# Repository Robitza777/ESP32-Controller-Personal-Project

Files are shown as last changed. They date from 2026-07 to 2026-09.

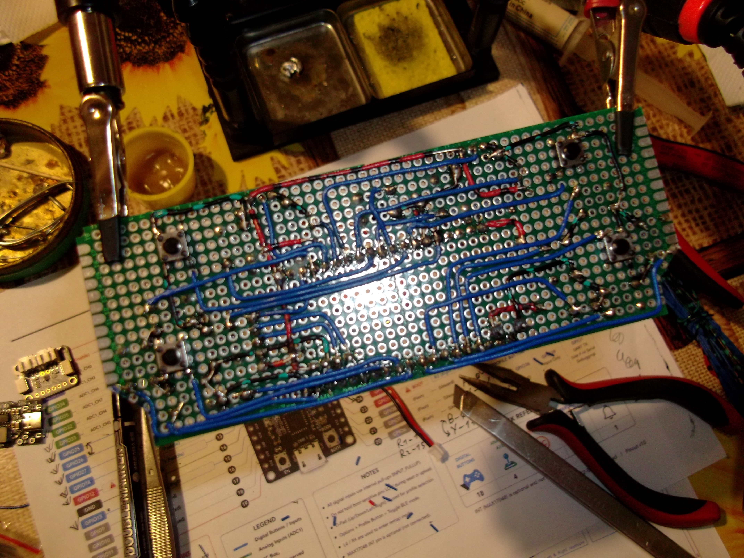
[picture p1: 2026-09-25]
media/hardware/Wiring.JPG

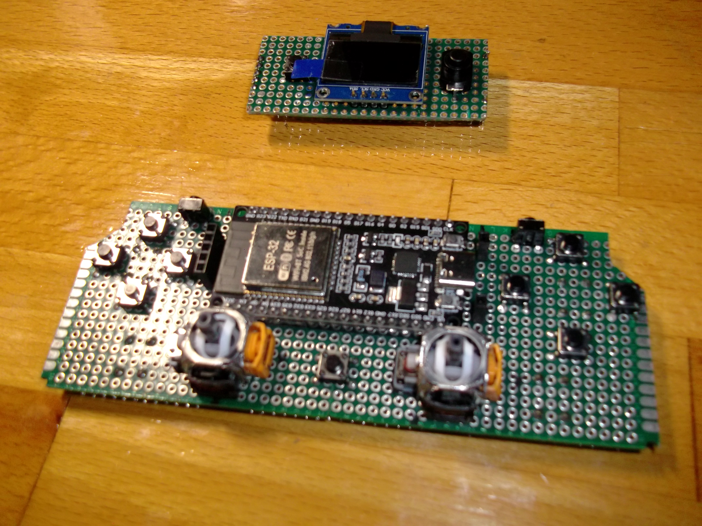
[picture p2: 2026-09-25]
media/hardware/Parts_Placement.JPG

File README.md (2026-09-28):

# ESP32-Controller-Personal-Project

A custom Bluetooth Low Energy gamepad controller built from scratch, combining hardware design, firmware development, and a fully 3D-printed enclosure. The goal of this project is a wireless gamepad that works **natively** in modern games (e.g. Fortnite) via true XInput support, with a flexible multi-profile system for gaming, desktop, and media use cases.

## Overview

This is not a modded off-the-shelf controller. Every major aspect is custom-designed:

* **Hardware** – ESP32-based electronics with hall-effect joysticks, dedicated battery management and fuel gauge, OLED status display, and a custom power system.
* **Firmware** – Native XInput over Bluetooth LE (not generic HID/DirectInput) together with keyboard, mouse, and media keys, featuring up to 16 profiles that are fully editable on the controller itself, battery monitoring, and automatic power-off.
* **Enclosure** – Fully custom 3D-printed shell, modeled in Blender and optimized around the project's hardware layout.

## Features

### Native XInput over Bluetooth LE

Unlike generic HID/DirectInput gamepads, this controller uses the [ESP32-BLE-CompositeHID](https://github.com/Mystfit/ESP32-BLE-CompositeHID) library to present itself as a native XInput device. This matters because many modern games, **Fortnite** being a notable example, do not recognize DirectInput controllers at all and previously required workarounds such as **x360ce**. With native XInput support, no additional software is needed.

The same Bluetooth connection also carries a keyboard, a 5-button mouse with vertical and horizontal scrolling, media keys, and system keys (sleep, power down). Any button can send any of them at any time, without re-pairing or switching modes. In Windows, the controller appears as **Robitza's ESP32 Gamepad**.

### Low Latency

Responsiveness is the firmware's top priority:

* All inputs are scanned at a fixed **1 kHz** on a dedicated CPU core.
* A button press registers on the very first sample (eager debounce, no added delay).
* The controller requests the shortest Bluetooth LE connection interval (**7.5 ms**) and sends a report only when something changed.
* Display, battery, and storage work runs on the other CPU core and never delays input.

### Profiles and Presets

The controller holds up to **16 profiles**, switchable at any time via the dedicated profile button. On first boot, it starts with four built-in presets:

| Profile | Description |
| --- | --- |
| **GAMEPAD**  | Native XInput controller. L4 acts as View, R4 as the Xbox Guide button. |
| **KB+MOUSE** | PC games without controller support (FPS layout). The left stick acts as WASD, the right stick controls the mouse, R2 / L2 are the left / right mouse buttons. |
| **MEDIA** | Desktop and media control: cursor, scrolling, volume, track control, play/pause, Alt+Tab, Win+D, copy and paste. |
| **HYBRID** | Standard XInput controller, plus a second layer while R4 is held: mouse, scrolling, clicks, Enter / Esc, and media keys, to operate the PC without leaving the game profile. |

Every profile can be edited, and new ones created, directly on the controller:

* Each button can send up to **three actions at once** (e.g. Ctrl+C, LB+RB, or an Xbox button plus a key), chosen from all Xbox buttons, the full keyboard (including F13–F24 and the numpad), mouse buttons and scrolling, and media, launch, browser, and system keys.
* Button modes: **Normal**, **Toggle** (press on / press off), and **Turbo** (1–20 presses per second).
* **RTZ layer** ("Robitza-Shift"): a button can switch the whole controller to a second set of mappings while held, or lock it in Toggle mode, similar to Razer HyperShift.
* Each stick can act as the left or right Xbox stick, a mouse, a scroll wheel, or four separate directions (WASD, arrow keys, D-pad...), with its own deadzone and speed.
* Any button or stick can be disabled.

### Profile Button

A dedicated profile button (GPIO36) switches profiles without any menu:

* **Short press** → Next profile.
* **Double press** → Back to the previous profile.
* **Hold + A / B / X / Y** → Jump to profile 1 / 2 / 3 / 4.
* **Hold for 3 seconds** → Open the configuration menu.

Buttons pressed while the profile button is held are never sent to the host.

### On-Controller Configuration Menu

All settings are changed directly on the controller's OLED screen, with no app, website, or reflashing required:

* **D-pad or left stick** to navigate, **A** to select, **B** to go back, **L1 / R1** to jump through long lists.
* To edit a button, simply **press it**.
* Create profiles from a preset or a copy of another profile, rename, reorder, and delete them.
* Controller settings: display brightness and timeout, automatic power-off times, stick recalibration, and Bluetooth pairing reset.
* Changes are kept only when leaving the menu with **Save**. While the menu is open, the host receives no input.

All profiles and settings are stored in the ESP32's Non-Volatile Storage (NVS), remaining available after power loss. The complete menu is described in the [User Guide](docs/UserGuide.md).

### OLED Status Display

A 0.96" SSD1306 OLED provides quick access to important controller information, including:

* Active profile name and number
* Battery percentage and a 4-bar indicator
* Charging status
* Bluetooth connection status
* RTZ layer and Toggle indicators

After a profile switch, the new name is shown full screen for a second. The screen switches off after a configurable time without input (30 seconds by default), and any input wakes it up.

### Battery Monitoring

A dedicated MAX17048 fuel gauge, connected directly across the battery terminals, provides accurate state-of-charge readings rather than relying solely on battery voltage.

The battery level is also reported to Windows and shown next to the device in the Bluetooth settings. At 5%, the controller shows a full-screen warning; at 2%, it switches itself off to protect the Li-Po cell.

### Power Management

The controller switches itself off after a configurable time without input (5 minutes by default, set separately for connected and not connected), after a 10-second on-screen countdown that any input cancels.

Rather than fighting the automatic shutdown behavior of the IP5306 / FM5324UI power module, which cuts its output when the load current stays too low, the firmware relies on it: the ESP32 enters deep sleep, the power module switches its 5 V output off about 30 seconds later, and the controller draws no power until the on/off switch is toggled.

### Hall-Effect Joysticks

Hall-effect joystick modules eliminate potentiometer wear and significantly reduce stick drift compared to traditional analog sticks.

The firmware measures each stick's center at power-on, scales every direction separately, and maps the sticks to a true circle (0% circularity error in a gamepad tester), with a per-profile radial deadzone. The centers can be measured again from the menu at any time.

## Hardware Platform

| Component | Purpose |
| --- | --- |
| ESP32 WROOM DevKit (38-pin) | Main microcontroller |
| IP5306 / FM5324UI | Battery charging & power management  |
| MAX17048 | Battery fuel gauge (state-of-charge) |
| SSD1306 0.96" OLED (I²C) | Status display |
| Ginfull R-5B / L-5C | Hall-effect joystick modules |
| Custom 3D-printed enclosure | Full physical housing |

Full schematics, pinouts, power design, bill of materials, and datasheets are available in [`hardware/`](hardware/).

## Firmware

Built with [PlatformIO](https://platformio.org/) targeting the ESP32 and powered by the [ESP32-BLE-CompositeHID](https://github.com/Mystfit/ESP32-BLE-CompositeHID) library, allowing simultaneous native XInput and keyboard/mouse HID functionality over Bluetooth Low Energy.

The firmware (version **1.0.0**) follows a modular architecture responsible for:

* Input processing
* Profile management
* On-controller configuration menu
* Bluetooth communication
* OLED display control
* Battery monitoring
* Power management
* Persistent storage (NVS)

Two builds are available: **release** (the default, flashed on the controller) and **debug** (the same firmware plus a detailed serial log for troubleshooting).

See [`firmware/`](firmware/) for the source code and build instructions, [`docs/Software.md`](docs/Software.md) for implementation details, and [`docs/Architecture.md`](docs/Architecture.md) for how the modules work together.

## Enclosure

The controller's shell is fully custom-designed and 3D-printed. Its overall shape and ergonomic layout are inspired by the **Alpakka 1 controller** by [Input Labs](https://github.com/inputlabs/cad), while the internal layout, mounting system, and component placement are unique to this project.

Blender source files, STEP exports, and printable STL models are available in [`enclosure/`](enclosure/).

## Repository Structure

```text
ESP32-Controller-Personal-Project/
├── firmware/      — PlatformIO firmware
├── hardware/      — Schematics, pinouts, power design, BOM, datasheets
├── enclosure/     — Blender source, STEP and STL exports
├── docs/          — User guide and technical documentation
├── media/         — Photos and videos of the enclosure, firmware and hardware
└── tools/         — Input tester
```

## Documentation

* [User Guide](docs/UserGuide.md)
* [Build Guide](docs/BuildGuide.md)
* [Hardware](docs/Hardware.md)
* [Software](docs/Software.md)
* [Architecture](docs/Architecture.md)
* [Development Log](docs/DevelopmentLog.md)
* [Future Plans](docs/FuturePlans.md)

## Project Status

Firmware **1.0.0** is complete and tested on the real hardware: all inputs, the four presets, the configuration menu, Bluetooth reconnection, battery monitoring, and automatic power-off. The project remains under active development.

See:

* [`CHANGELOG.md`](CHANGELOG.md) for released milestones.
* [`docs/DevelopmentLog.md`](docs/DevelopmentLog.md) for ongoing development progress.
* [`docs/FuturePlans.md`](docs/FuturePlans.md) for ideas being considered.

## Contributing

Contributions, suggestions, and bug reports are welcome.

Please read [`CONTRIBUTING.md`](CONTRIBUTING.md) before opening issues or pull requests.

## License

See [`LICENSE`](LICENSE) for licensing information.

## Acknowledgements

* Enclosure design inspired by the [Alpakka 1 controller](https://github.com/inputlabs/cad) by **Input Labs**.
* Built on top of the [ESP32-BLE-CompositeHID](https://github.com/Mystfit/ESP32-BLE-CompositeHID) library by **Mystfit**, included in [`firmware/lib/`](firmware/lib/) with local changes.
* Bluetooth LE stack: [NimBLE-Arduino](https://github.com/h2zero/NimBLE-Arduino) by **h2zero**.
* OLED graphics: [U8g2](https://github.com/olikraus/u8g2) by **olikraus**.
* Fuel gauge driver: [SparkFun MAX1704x Fuel Gauge Arduino Library](https://github.com/sparkfun/SparkFun_MAX1704x_Fuel_Gauge_Arduino_Library) by **SparkFun Electronics**.

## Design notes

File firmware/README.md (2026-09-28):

# Firmware

PlatformIO project for the controller's ESP32, firmware version **1.0.0**. How the firmware works is described in [`docs/Software.md`](../docs/Software.md) and [`docs/Architecture.md`](../docs/Architecture.md); how to use the controller in [`docs/UserGuide.md`](../docs/UserGuide.md).

## Requirements

* [VS Code](https://code.visualstudio.com/) with the [PlatformIO IDE](https://platformio.org/install/ide?install=vscode) extension (or the PlatformIO Core CLI).
* A USB cable to the ESP32 DevKit (CP2102 USB-serial chip; Windows may need the Silicon Labs CP210x driver).

Everything else (the ESP32 toolchain, Arduino core, and libraries) is downloaded by PlatformIO on the first build, at the exact versions pinned in [`platformio.ini`](platformio.ini).

## Build and Flash

Open **this folder** (`firmware/`, the one containing `platformio.ini`) in VS Code, not the repository root.

| Build | What it is | Command |
|---|---|---|
| `release` | The default. What stays on the controller: no serial output. | `pio run -t upload` |
| `debug` | The same firmware, plus a serial log: Bluetooth pairing and connection, battery readings, power decisions, saves. | `pio run -e debug -t upload` |

In VS Code, the same actions are under **PlatformIO → Project Tasks → release / debug → Upload**. To read the debug log, open the serial monitor (`pio device monitor`, 115200 baud) after uploading.

Uploading only replaces the program: saved profiles, settings, and Bluetooth pairings are kept.

**Don't hold any button while the board resets or is being flashed.** A, X, D-pad Up, R2, and R4 are on ESP32 boot pins (see [`Pinout.md`](../hardware/pinout/Pinout.md)).

### First Flash

The project uses its own partition table ([`partitions.csv`](partitions.csv)) with a larger settings store (NVS, 128 KB). If the board was previously flashed with a different partition table, erase it once with **PlatformIO → Project Tasks → release → Platform → Erase Flash** before uploading. Erasing also removes the Bluetooth pairing, so the controller must be removed and paired again in Windows.

## Folder Structure

```text
firmware/
├── platformio.ini     — Board, libraries (pinned versions), release and debug builds
├── partitions.csv     — Flash layout: app 3 MB, NVS 128 KB
├── include/           — Module headers: public interface and design notes
│   ├── Config.h       — Every pin, address, timing and threshold
│   └── ...
├── src/               — Module implementations; main.cpp starts the tasks and connects the modules
└── lib/
    └── ESP32-BLE-CompositeHID/   — Vendored library with local changes (see its VENDORED.md)
```

| Module | Files | Responsibility |
|---|---|---|
| main | `main.cpp` | Starts the input and UI tasks, passes data between modules, runs the menu hand-off and the power-off sequence |
| InputReader | `InputReader.h/.cpp` | Buttons and sticks: debounce, stick calibration, circular mapping, deadzone |
| ProfileButton | `ProfileButton.h/.cpp` | Profile button gestures |
| Profiles | `Profiles.h/.cpp`, `ProfileTypes.h` | Presets, profile list, and the engine that turns inputs into outputs |
| ConfigMenu | `ConfigMenu.h/.cpp`, `MenuView.h` | The on-controller configuration menu |
| ActionCatalog | `ActionCatalog.h/.cpp`, `HidUsages.h` | Named, grouped action lists offered by the menu |
| BleOutput | `BleOutput.h/.cpp` | Bluetooth LE HID device: Xbox controller, keyboard, media keys, mouse |
| Display | `Display.h/.cpp` | OLED: status screen, menu, alerts |
| BatteryMonitor | `BatteryMonitor.h/.cpp` | MAX17048 fuel gauge |
| PowerManager | `PowerManager.h/.cpp` | Automatic power-off and battery protection |
| Storage | `Storage.h/.cpp` | Profiles and settings in NVS |
| (shared) | `ControllerTypes.h`, `Log.h` | Data types passed between modules, debug logging |

## Libraries

| Library | Version | Used for |
|---|---|---|
| [ESP32-BLE-CompositeHID](https://github.com/Mystfit/ESP32-BLE-CompositeHID) | commit `032b064`, vendored in `lib/` | Xbox controller + keyboard + mouse over one BLE connection |
| [NimBLE-Arduino](https://github.com/h2zero/NimBLE-Arduino) | 2.5.1 | Bluetooth LE stack |
| [Callback](https://github.com/tomstewart89/Callback) | 1.1 | Required by ESP32-BLE-CompositeHID |
| [U8g2](https://github.com/olikraus/u8g2) | 2.36.18 | SSD1306 OLED |
| [SparkFun MAX1704x Fuel Gauge](https://github.com/sparkfun/SparkFun_MAX1704x_Fuel_Gauge_Arduino_Library) | 1.0.4 | MAX17048 fuel gauge |

Platform: `espressif32 @ 7.0.1` (Arduino core 2.0.17, ESP-IDF 4.4), C++17.

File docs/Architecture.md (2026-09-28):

# System Architecture

## Overview

The ESP32 Controller firmware is structured as a modular embedded system where hardware input, profile logic, persistent configuration, BLE communication, power monitoring, and user feedback are separated into independent components.

The architecture is designed around a central control flow, split across the ESP32's two CPU cores:

```
CORE 1 — input task, every 1 ms
-------------------------------
Hardware Inputs
      |
      v
InputReader
      |
      v
ProfileButton / Profiles
      |
      +----------------------------+
      |                            |
      v                            | status snapshot
BleOutput                          | (profile, layer, last activity)
      |                            |
      v                            |
Bluetooth LE HID                   |
                                   |
CORE 0 — UI task, every 20 ms      |
-----------------------------      |
main.cpp (UI loop) <---------------+
      |
      +----> PowerManager
      |
      +----> ConfigMenu ----> Storage ----> ESP32 NVS
      |
      +----> Display -------> SSD1306 OLED
      |
      +----> BatteryMonitor <---- MAX17048 <---- Battery
```

The main firmware entry point (`main.cpp`) acts as the orchestrator, initializing modules and coordinating communication between them.

---

# Task Layout

The firmware runs two FreeRTOS tasks, one per CPU core. Responsiveness comes first: nothing slow is allowed on the path from a button to the Bluetooth report.

| Task | Core | Priority | Period | Work |
|---|---|---|---|---|
| **input** | 1 | high (10) | 1 ms, fixed (`vTaskDelayUntil`) | `InputReader` → `ProfileButton` / `Profiles` → `BleOutput` |
| **UI** | 0 | low (1) | 20 ms | `Display`, `BatteryMonitor`, `PowerManager`, `ConfigMenu`, `Storage` writes |

* The NimBLE Bluetooth host also runs on core 0, above the UI task, so slow UI work never delays Bluetooth either.
* A full OLED frame takes about 23 ms of I²C traffic, and a flash write can stall both cores; both happen only in the UI task, and the display redraws only when something shown has changed.
* The UI task is the **only** user of the I²C bus, so the bus needs no locking.
* The input path never blocks: no `delay()`, no I²C, no flash writes, no serial output.
* The input task publishes a small status snapshot (active profile, layer and toggle state, time of the last activity) every cycle; the UI task reads it every cycle. Both copy a few bytes under a spinlock, so neither side waits noticeably.

Measured input cycle: about 170 µs with nothing to send, about 0.5 ms when a report goes out, rarely up to about 1 ms.

---

# Firmware Layers

## Application Layer

### main.cpp

`main.cpp` is responsible for:

* Loading the saved profiles and settings, initializing all firmware modules, and starting the two tasks.
* Running the input loop and the UI loop.
* Coordinating input processing, profile handling, BLE output, and display updates.
* Handing the profile list over to the configuration menu and back (see below).
* Running the power-off sequence.

Individual modules should not directly depend on each other where possible. Communication should happen through clearly defined interfaces: modules exchange plain data structures (`InputState`, `OutputReport`, `BatteryStatus`, `Profile`...) and `main.cpp` passes them along.

---

# Input Layer

## InputReader

The `InputReader` module handles all physical controller inputs.

Responsibilities:

* Reading digital button states (both GPIO registers in one go).
* Reading analog joystick values (ADC1 through the IDF low-level HAL, oversampled).
* Applying joystick calibration, circular mapping, and deadzone processing.
* Eager debouncing, and the ESP32 GPIO36/39 errata workaround.
* Converting raw hardware values into normalized controller data.

Input flow:

```
Buttons
Joysticks
   |
   v
InputReader
   |
   v
InputState (18 buttons as a bitmask, 4 axes in -32767..32767, +X right, +Y up)
```

The module abstracts the physical GPIO layout from the rest of the firmware.

---

# Profile System

## Profiles

The profile system controls how controller inputs are interpreted.

Built-in presets (read-only templates in flash):

* GAMEPAD
* KB+MOUSE
* MEDIA
* HYBRID

The user's profile list (up to 16) starts as one profile per preset and is then edited in the configuration menu. The profile layer receives normalized controller input and decides how it should be translated, through the active profile's layer (base or RTZ).

Example:

```
Joystick Movement
        |
        v
     Profiles
        |
        +------> XInput Axis
        |
        +------> Mouse Movement / Scroll
        |
        +------> Keyboard Keys (4-way mode)
```

The result is one `OutputReport` per input cycle: the complete state the host should see (Xbox controller, keyboard, consumer keys, system keys, mouse).

---

# Profile Button State Machine

## ProfileButton

The profile button provides access to profile switching and configuration functions without requiring external software.

State flow:

```
Normal Operation

      |
      +---- Short press ----------------> Next profile
      |
      +---- Double press ---------------> Previous profile
      |
      +---- Hold + A / B / X / Y -------> Profile 1 / 2 / 3 / 4
      |
      | Hold 3 s alone
      v

Configuration Menu

      |
      | Hold 3 s again → Save / Discard / Keep editing
      v

Normal Operation
```

Buttons pressed while the profile button is held are kept from the host until they are released.

---

# Configuration Menu

## ConfigMenu, MenuView, ActionCatalog

The configuration menu runs in the UI task:

* `ConfigMenu` holds the menu logic: pages, cursor, the edits.
* `MenuView` is a text-only description of one screen (title, rows, values, cursor). `ConfigMenu` fills it, `Display` draws it: the menu logic never deals with fonts or pixels.
* `ActionCatalog` holds the named, grouped action lists the menu offers (None, RTZ layer, Gamepad, Keyboard, Mouse, Media & system).

While the menu is open, the input task sends the host a neutral report and forwards the buttons and the left stick to the menu. The profile list is handed over between the two tasks with a small state machine, so that only one task works on it at a time:

```
Closed
   |
   | Profile held 3 s: the input task copies the profiles into the menu's workspace
   v
Open  ---- the UI task edits the workspace; the host receives a neutral report
   |
   +---- Save ------> UI task writes the changes to NVS
   |                        |
   |                        v
   |                  Saved: the input task takes the new list into Profiles
   |
   +---- Discard ---> Discarded: the input task keeps its profiles
   |
   v
Closed
```

The workspace also carries the display and power settings; display changes are previewed live while the menu is open.

---

# Storage Layer

## Storage

The storage module provides persistent configuration using ESP32 NVS (Non-Volatile Storage).

Stored data includes:

* The profile list (up to 16 profiles, with a format version).
* Active profile selection.
* Display settings (brightness, screen timeout, name popup).
* Automatic power-off times.

Storage flow:

```
Configuration Menu (Save)
Profile switch (after 3 s)
        |
        v
Storage Module (UI task only)
        |
        v
ESP32 NVS
```

Settings remain available after power loss or restart. The Bluetooth pairings are stored separately by NimBLE.

---

# Communication Layer

## BleOutput

The `BleOutput` module acts as an abstraction layer over the BLE HID implementation.

Responsibilities:

* Sending XInput reports.
* Sending keyboard, consumer (media) and system key reports.
* Sending mouse reports.
* Reporting the battery level to the host.
* Erasing the pairings, and closing the connection before a power-off.

Flow:

```
OutputReport
        |
        v
   BleOutput (a report per device, only when it changed)
        |
        v
ESP32-BLE-CompositeHID
        |
        v
NimBLE ----> Bluetooth LE Device (Xbox controller + keyboard + mouse)
```

The system supports simultaneous controller and HID functionality through the ESP32-BLE-CompositeHID library.

---

# Display Layer

## Display

The OLED display provides user feedback.

Displayed information includes:

* Active profile (name and number), with a full-screen popup after a switch.
* Battery status (percentage, bars, charging).
* Bluetooth connection status.
* RTZ layer and Toggle indicators.
* The configuration menu.
* Full-screen alerts (power-off countdown, battery warnings).

Flow:

```
Status snapshot + BatteryStatus    MenuView    Power alert
             |                        |             |
             v                        v             v
                         Display Module
                               |
                               v
                          SSD1306 OLED
```

The display communicates through the shared I²C bus. It is mounted rotated 180°, redraws only when something shown has changed, and switches off after the configured time without activity.

---

# Battery Monitoring Layer

## BatteryMonitor

The battery monitoring system uses the MAX17048 fuel gauge.

Responsibilities:

* Reading battery state-of-charge every 5 seconds.
* Detecting charging from the gauge's charge rate.
* Providing battery information to the display, the power manager, and the host.
* Handling battery monitoring independently from the charging/power management circuit.

Flow:

```
Battery
   |
   v
MAX17048
   |
   v
BatteryMonitor
   |
   +----> Display
   |
   +----> PowerManager
   |
   +----> BleOutput (Battery Service)
```

---

# Hardware Communication

## I²C Bus

The controller uses a shared I²C bus at 400 kHz:

```
ESP32
 |
 +---- SDA GPIO21
 |
 +---- SCL GPIO22
        |
        +---- SSD1306 OLED (0x3C)
        |
        +---- MAX17048 (0x36)
```

Both devices operate on different I²C addresses and can coexist on the same bus. Only the UI task uses the bus.

---

# Power Management

## PowerManager

The power management module decides when to warn the user and when to power off:

* Automatic power-off after the configured time without activity, with a 10-second countdown.
* Battery critical warning at 5%.
* Automatic power-off at 2% to protect the battery.

Power-off sequence (`main.cpp`):

```
PowerManager: power off
        |
        v
Input task stops sending
        |
        v
OLED off, Bluetooth connection closed
        |
        v
ESP32 deep sleep (no wake-up source)
        |
        v
Load below the power module's threshold ----> 5 V output switched off (~30 s later)
        |
        v
Controller off until the on/off switch is toggled
```

The firmware can switch the controller off, but not on. Light sleep is not used while the controller is on, because the lower current draw would make the power module cut the power in the middle of use.

---

# Design Principles

The firmware architecture follows these principles:

* **Responsiveness first** — nothing on the path from a button to the Bluetooth report may block or wait for slow work.
* **Modularity** — each hardware/software function has its own module.
* **Separation of concerns** — input processing, output generation, storage, and display logic remain independent.
* **Hardware abstraction** — physical GPIO assignments should not leak into higher-level logic; every pin, address, and timing lives in `Config.h`.
* **Graceful degradation** — the controller keeps working if the display or the fuel gauge is missing.
* **Maintainability** — new profiles, mappings, and features should be added without rewriting core functionality.
* **Expandability** — the architecture supports future features such as a companion configuration tool, macros, and OTA updates.

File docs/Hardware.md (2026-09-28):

# Hardware Overview

## Core Components

| Component | Role |
|---|---|
| ESP32 WROOM DevKit (38-pin, CP2102) | Main microcontroller, handles input reading, BLE communication, and firmware logic |
| Ginfull R-5B / L-5C hall-effect joysticks | Analog stick input, chosen for durability and drift resistance over potentiometer sticks |
| MAX17048 | Battery fuel gauge (I²C `0x36`) — provides accurate state-of-charge readings |
| IP5306 / FM5324UI | Battery charging and 5 V power delivery |
| SSD1306 OLED 128x64 (I²C `0x3C`) | Status display and configuration menu, mounted rotated 180° |
| 1S Li-Po battery, 3.7 V 2500 mAh | Power source |
| Custom protoboard | Houses all electronics |

## Power Architecture

- The **IP5306 / FM5324UI** module charges the 1S Li-Po battery and delivers 5 V to the ESP32 DevKit's `5V` pin.
- A physical **on/off switch** in the 5 V line, between the power module and the ESP32, disconnects the system power completely. The module's `K` (KEY) pin is **not used**: it was tested and did not provide the expected power control behavior in this hardware implementation.
- The power module switches its 5 V output off by itself when the load current stays below its minimum (about 45–50 mA) for about 30 seconds. While the controller is on, the ESP32 with its Bluetooth radio draws enough to stay above that threshold, so the firmware doesn't use light sleep or CPU down-clocking. The firmware uses this behavior for its **automatic power-off**: the ESP32 enters deep sleep, the module cuts the 5 V output about 30 seconds later, and the on/off switch (off, then on) starts the controller again. The firmware can switch the controller off, but not on.
- The **MAX17048** fuel gauge is wired directly across the battery terminals, in parallel with the charging circuit. This placement means it reads the battery's true state without interfering with charging, and it keeps tracking the battery while the controller is switched off. Its `INT` pin is not connected.

<!-- Full details in [PowerDesign.md](../hardware/power/PowerDesign.md) and [BatteryCalibration.md](../hardware/power/BatteryCalibration.md). -->

## GPIO Considerations

GPIO36 (used for the profile button) and GPIO39 (D-pad Down) are **input-only pins with no internal pull-up**, requiring an external 10kΩ pull-up resistor to 3.3V each. This is a hard hardware constraint of the ESP32 and must be accounted for in the wiring.

- **GPIO2** (X button) is tied to the DevKit's on-board LED and needs an external 1 kΩ pull-up resistor to 3.3 V to be read reliably.
- **Boot strapping pins** — GPIO0 (A), GPIO2 (X), GPIO5 (D-pad Up), GPIO12 (R4) and GPIO15 (R2) affect the ESP32 boot process: their buttons must not be held while the controller is switched on, reset, or flashed.
- **ESP32 errata** — GPIO36 and GPIO39 can briefly read LOW when the ADC powers up. The firmware works around it (the ADC stays powered and these two pins need two LOW readings in a row).
- **Joysticks** use ADC1 (GPIO32–35), because ADC2 can't be used while Bluetooth is active. The Ginfull sticks' raw output covers the full 0–4095 range and saturates at both ends before full travel; the firmware calibrates and scales it.
- **L2 / R2** are digital buttons, not analog triggers.

Full pin assignments are documented in [`Pinout.md`](../hardware/pinout/Pinout.md).

## Assembly Notes

The ESP32 DevKit sits in female headers (socketed, not soldered). A board that isn't pushed fully into its headers can lose contact on its `5V` pin under vibration, which shows up as random power-offs and can also disturb the stick readings (a stick that no longer rests at zero). If random resets or power-offs appear, check the seating of the board first.

## Enclosure

All electronics — ESP32, protoboard, joysticks, power management, fuel gauge, and OLED are held together by the **back shell** (`green_back.stl`) and the **front shell** (`black_front.stl`), which are purely mechanical, providing only cutout windows for buttons, sticks, and the display; no components attach to them directly.

The OLED display, profile button and on/off switch are mounted on a suspended support platform.

The overall shell shape and ergonomics are inspired by the **Alpakka 1 controller by Input Labs**, adapted to this project's specific internal component layout.

See [`enclosure/`](../enclosure/) for 3D source files and exports, and [`hardware/schematics/`](../hardware/schematics/) for circuit schematics.

## Datasheets

Component datasheets are available in [`hardware/datasheets/`](../hardware/datasheets/):
- ESP32
- MAX17048
- IP5306 / FM5324UI
- SSD1306

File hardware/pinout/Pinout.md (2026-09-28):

# GPIO Pinout

This document describes the GPIO assignments used by the ESP32-Controller-Personal-Project.

---

## Digital Inputs

| Function | GPIO | Notes |
|---|---|---|
| A Button (Down) | GPIO0 | Boot strapping pin (flashing mode). Do not hold during power-on or firmware flashing. |
| B Button (Right) | GPIO17 | Standard digital input. Uses internal `INPUT_PULLUP`. |
| X Button (Left)| GPIO2 | Strapping pin tied to on-board LED. Requires an external 1 kΩ pull-up resistor to function reliably. Do not hold during power-on or firmware flashing. |
| Y Button (Up) | GPIO4 | Standard digital input. Uses internal `INPUT_PULLUP`. |
| D-Pad Up | GPIO5 | Boot strapping pin (SDIO timing). Avoid holding during reset. |
| D-Pad Down | GPIO39 | Input-only pin (GPI). Lacks internal pull resistors; requires an external 10 kΩ pull-up resistor. |
| D-Pad Left | GPIO23 | Standard digital input. Uses internal `INPUT_PULLUP`. |
| D-Pad Right | GPIO13 | Standard digital input. Uses internal `INPUT_PULLUP`. |
| R1 (Right Shoulder) (Up) | GPIO16 | Standard digital input. Uses internal `INPUT_PULLUP`. |
| R2 (Right Trigger) (Down) | GPIO15 | Boot strapping pin (ROM boot logging). Avoid holding during reset. |
| R3 (Right Joystick Click) | GPIO26 | Standard digital input. Uses internal `INPUT_PULLUP`. |
| R4 (Back Paddle) | GPIO12 | Boot strapping pin (flash VDD voltage). Critical: do not pull HIGH at boot. |
| L1 (Left Shoulder) (Up) | GPIO18 | Standard digital input. Uses internal `INPUT_PULLUP`. |
| L2 (Left Trigger) (Down) | GPIO19 | Standard digital input. Uses internal `INPUT_PULLUP`. |
| L3 (Left Joystick Click) | GPIO25 | Standard digital input. Uses internal `INPUT_PULLUP`. |
| L4 (Back Paddle) | GPIO14 | Standard digital input. Uses internal `INPUT_PULLUP`. |
| Options (Middle) | GPIO27 | Standard digital input. Uses internal `INPUT_PULLUP`. |
| Profile Button | GPIO36 |Input-only pin (GPI). Lacks internal pull resistors; requires an external 10 kΩ pull-up resistor. |

---

## Analog Inputs

| Function | GPIO | ADC Channel |
|---|---|---|
| Left Stick X (Black) | GPIO34 | ADC1_CH6 |
| Left Stick Y (Orange) | GPIO35 | ADC1_CH7 |
| Right Stick X (Black) | GPIO32 | ADC1_CH4 |
| Right Stick Y (Orange) | GPIO33 | ADC1_CH5 |

---

## I²C Devices

Both devices share the same I²C bus.

| Device | SDA | SCL | Notes |
|---|-----|-----|---|
| MAX17048 Fuel Gauge | GPIO21 | GPIO22 | Requires 10 kΩ pull-up resistors to 3.3V if not included in the boards (in my case i didn't need external pull-up) |
| SSD1306 OLED Display | GPIO21 | GPIO22 | Shares the bus with MAX17048. Verify I²C addresses if additional devices are added. |

---

## Optional Connections

| Function | Recommendation |
|---|---|
| MAX17048 INT | Leave unconnected (not used in this build). No free GPIO is left for it: GPIO39 is now D-Pad Down, and GPIO1 / GPIO3 are reserved. The firmware reads the fuel gauge every 5 seconds instead. |

---

## Reserved GPIOs

| GPIO | Reason |
|---|---|
| GPIO1 (TX0) | USB serial (CP2102): firmware upload and the Serial Monitor. Keep free. |
| GPIO3 (RX0) | USB serial (CP2102). A button on this pin interferes with the Serial Monitor. Keep free. |

---

# Boot-Sensitive Pins

The following GPIOs affect the ESP32 boot process and **must not be held LOW during reset or upload**:

- GPIO0
- GPIO2
- GPIO5
- GPIO12
- GPIO15

These pins are safe to use for buttons as long as the user is not pressing them while the board is powering up or resetting.

---

# I²C Bus

```
GPIO21 (SDA)
        │
        ├── MAX17048
        └── SSD1306 OLED

GPIO22 (SCL)
        │
        ├── MAX17048
        └── SSD1306 OLED
```

---

# Summary

| Category | Count |
|---|---:|
| Digital buttons | 18 |
| Analog axes | 4 |
| I²C devices | 2 |
| Reserved GPIOs | 2 |
| Optional interrupt lines | 1 |

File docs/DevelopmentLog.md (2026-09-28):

# Development Log

A chronological log of design decisions, findings, and progress on the ESP32 BLE Gamepad project.

---

## 2026-07-06 — Initial Firmware Review and Redesign Decisions

- Reviewed existing firmware based on ESP32-BLE-Gamepad (lemmingDev), v0.5.4.
- Identified that the library implements DirectInput / generic HID, not XInput — root cause of games (e.g. Fortnite) not recognizing the controller natively.
- Identified additional bugs:
  - Joystick axis mapping outputs unsigned range (0 → 32767) instead of signed (-32767 → 32767).
  - Deadzone variable declared but never applied.
  - Blocking `delay()` calls present in the main loop.
  - No button debounce.
  - Unsafe battery sensor initialization (no fallback if sensor absent).
  - Pin assignments in the "stable" firmware variant inconsistent with actual physical hardware (Experimental variant + `Pins.txt` confirmed as the correct reference).
- Tagged as `[0.1.0]` in CHANGELOG — first known-working baseline, with all issues above logged as Known Issues.
- Decided to migrate to **ESP32-BLE-CompositeHID** (Mystfit fork) to get native XInput plus simultaneous keyboard/mouse HID support.
- Designed the **4-profile system**: GAMEPAD, KEYBOARD+MOUSE, HYBRID, DESKTOP/MEDIA.
- Designed the profile button state machine (GPIO36): hold ≥0.5s to arm, D-pad to select profile, L4/R4 to enter remap mode, Options to reset BLE pairing, timeout/re-press to cancel.
- Defined L4/R4 alias remapping behavior: after entering remap mode, the next physical button pressed is automatically captured and saved as the new alias in NVS — no menu navigation required.
- Confirmed GPIO36 (input-only, no internal pull-up) requires an external 10 kΩ pull-up to 3.3V for the profile button.
- Reserved GPIO39 and GPIO1 for future use.
- Defined power wiring: FM5324UI battery on BAT+/BAT−, 5V out to DevKit V5 pin, KEY pin routed through a physical on/off button to GND.
- Defined MAX17048 wiring: connected in parallel directly across battery terminals, sharing GND with the rest of the system.
- Confirmed OLED and MAX17048 share the I2C bus (SDA = GPIO21, SCL = GPIO22) with no address conflict.
- Decided on **light sleep** (not deep sleep) for power management, to avoid triggering the FM5324UI's auto-shutoff below ~50 mA draw.
- Set 4.15V as a placeholder threshold for charging detection, pending empirical calibration.
- Identified the need for a separate suspended mounting platform (above the ESP32 module) to hold the OLED and the two square buttons (on/off + profile) — to be designed.
- Noted that joystick pinouts differ between the R-5B and L-5C modules and require verification (ConsoleMods Wiki or multimeter) before final wiring.

## 2026-07-07 — Toolchain Migration and OLED Testing

- Migrated firmware project from Arduino IDE to **PlatformIO**, run via the PlatformIO IDE extension in VS Code.
- Reasoning: real folder structure (`src/`, `include/`, `lib/`) matches the desired modular code organization and works properly with Git, unlike Arduino IDE's tab-based sketches.
- Defined `.h`/`.cpp` convention: each module has a matching pair (`include/ModuleName.h` for declarations, `src/ModuleName.cpp` for implementation), except `main.cpp`, which has no header pair.
- Built a standalone PlatformIO test project (`OLED_Test_PlatformIO/`) to validate the SSD1306 128x64 display at I2C address 0x3C.
- Used `esp32dev` board target with `Adafruit GFX Library` and `Adafruit SSD1306` via `lib_deps`.
- Test sketch includes a visual heartbeat (counter + animated bar) and explicit error handling if the display doesn't respond at the expected address.
- Hit a blocker: `command 'platformio-ide.build' not found` error in VS Code after installing the PlatformIO IDE extension — known issue, typically caused by an incomplete background Core install, needing a VS Code restart, or Python interpreter conflicts (common on Windows).

## 2026-07-08 — GitHub Repository Organization and Small Progress

- Defined final repository structure: `firmware/`, `hardware/`, `enclosure/`, `docs/`, `images/`, `videos/`, `tools/`, plus top-level `README.md`, `LICENSE`, `.gitignore`, `CHANGELOG.md`, `CONTRIBUTING.md`.
- Decided all GitHub-facing content (docs, code comments, commit messages) is written in English.
- Generated `README.md` — project overview, features, hardware table, repository structure, documentation index, and acknowledgements (crediting the **Alpakka 1 controller by Input Labs** as the enclosure's design inspiration).
- Generated `CHANGELOG.md` in Keep a Changelog format, covering `[Unreleased]` (redesign work) and `[0.1.0]` (initial working baseline with Known Issues).
- Modified the front enclosure design to integrate the OLED display while maintaining clearance for internal components.
- Experimentally determined the joystick pinouts by disassembling a damaged PS4 controller and tracing the motherboard connections, providing a verified reference for wiring.
- Continued development of the suspended internal mounting platform for the OLED display, refining its positioning and structural support.
- Experimentally verified that the FM5324UI module's KEY pin does not provide the expected power control behavior in this hardware implementation.
- Updated the power system design to replace the KEY-pin-controlled power function with a dedicated inline physical on/off switch that completely disconnects system power.
- Printed a test part to see the screen tolerances and placement on the suspended internal mounting platform.
- Adjusted the stl file `black_front` again after the test.
- Sanded the ESP32 mounting supports to gain more clearance.
- Fixed The screen hole going through the top cover (made me actually happy for some reason).

## 2026-07-16 — Schematic and Pinout Update

- Created the complete electrical schematic for the controller hardware.
- Added the finalized schematic to the GitHub repository documentation.
- Experimentally verified the I²C pull-up resistor configuration of the MAX17048 and SSD1306 modules, confirming that external pull-up resistors are unnecessary.
- Updated `Pinout.md` with a clearer description of the physical layout and positioning of the buttons and joysticks.
  
## 2026-07-17 — Power Management Findings and Documentation Updates

- Experimentally determined that the FM5324UI automatically disables its 5V output after approximately 30 seconds when the load current is below its minimum threshold.
- Identified this behavior as a potential blocker for implementing the planned light/deep sleep functionality, since the reduced power consumption during sleep may trigger an unintended power shutdown (further investigation needed).
- Expanded the project documentation by adding `Bluetooth.md`, `Features.md`, `FuturePlans.md`, `Hardware.md`, and `Software.md` to the `docs/` directory.
- Added `CONTRIBUTING.md` to the repository, providing guidelines for future contributions and development workflow.

## 2026-07-18 — Repository Documentation Restructuring

- Restructured the repository documentation to reduce duplication and improve maintainability.
- Merged `Features.md` into `README.md`, consolidating the project overview and feature descriptions into a single entry point.
- Merged `Bluetooth.md` into `Software.md`, keeping communication architecture and BLE implementation details together with the firmware documentation.
- Merged `Battery.md` into `Hardware.md`, consolidating power architecture and battery management information with the hardware documentation.
- Simplified the `docs/` directory structure to make project information easier to navigate and reduce maintenance overhead.
- Added `Architecture.md` to the `docs/` directory to document the overall system design, module relationships, communication flow, and firmware architecture.
- Added `Pinout.png` to the `hardware/pinout/` directory to provide a visual reference for the physical board orientation and component placement.

## 2026-09-05 — Assembly and Enclosure Adjustments

- Started soldering the components into their final positions on the circuit boards.
- Cut the ESP32 pins to allow the module to fit underneath the secondary circuit board.
- Identified an issue with the placement of the L1 and R1 switches and planned to reposition them.
- Modified `black_front` to improve the enclosure fit; further testing is required.
- Modified `green_thumbstick_x2` to provide better clearance around the electrical components.

## 2026-09-07 — Enclosure and Component Placement Adjustments

- Fixed the placement of the L1 and R1 switches.
- Fixed an issue with the R1 button clearance in `black_front`.
- Adjusted the `green_abxy_x4`, `green_dpad_x4`, `green_home`, and `green_on_off` buttons to fit the new switch placement.
- Moved the joystick holes to align with their positions on the circuit board.
- Lowered the on/off button position to improve its fit within the enclosure.
- Tested a new method for preventing overhang edges from sagging, aiming to achieve a cleaner perimeter around the screen opening.

## 2026-09-18 — Hardware Wiring and Pin Assignment Testing

- Started making the electrical connections between the hardware components.
- Swapped the GPIO assignments of the L3 and R3 buttons, resulting in L3 → GPIO25 and R3 → GPIO26.
- Tested the analog joystick axes and several buttons using dedicated test firmware to verify their functionality.
- Discovered that connecting a button to GPIO3 interferes with the Serial Monitor. Planned to move the B button to GPIO39 and add an external 10 kΩ pull-up resistor to 3.3 V.
- Considered changing the GPIO assignments of additional buttons to improve cable routing and reduce wiring complexity.
- Any further pin assignment changes will be reflected in `Pinout.md`, `Pinout.png`, and the electrical schematic.

## 2026-09-25 — Final Hardware Wiring and Pinout Updates

- Finished the electrical connections between the hardware components.
- Adjusted the wiring of several pins to improve cable routing and overall wire management (added a 10 kΩ pull-up resistor from 3.3v to the GPIO39).
- Experimentally determined that the button connected to GPIO2 was being read as permanently pressed. Added a 1 kΩ pull-up resistor to 3.3 V to resolve the issue.
- Updated `Pinout.md`, `Pinout.png`, and the electrical schematic to reflect all wiring and pin assignment changes.
- Added the first media files documenting the electrical component placement, wiring, and functionality of the test firmware.

## 2026-09-26 — Firmware Rewrite and Bluetooth Composite Test

- Added `Test_Code_Compressed.mp4` to media to hopefully allow for web viewing of the video.
- Fixed `Pinout.md` Digital Inputs Table.
- Started the 1.0.0 firmware from scratch as a modular PlatformIO project (one `.h`/`.cpp` module per function, every pin and timing in `Config.h`), with responsiveness as the top priority.
- Built a standalone test firmware for **ESP32-BLE-CompositeHID**: an Xbox controller, a keyboard, media keys, and a mouse on one Bluetooth connection. Windows bound its native Xbox driver (`xinputhid`), and all four devices worked together.
- Experimentally determined that Windows rejects the device ("driver error", Code 10) when the combined HID report map is larger than 512 bytes. The Xbox One S configuration with keyboard, media keys, and mouse needs about 546 bytes; switched to the Xbox **Series** configuration (about 495 bytes).
- Verified that the host reconnects without re-pairing after a power cycle, and that Windows accepts the shortest connection interval (7.5 ms).
- Determined the stick directions: the raw X value falls when a stick is pushed right, the raw Y value rises when it is pushed up.

## 2026-09-27 — Core Firmware Modules

- Defined the task layout: a 1 kHz input task on core 1 (buttons → profiles → Bluetooth) and a slower UI task on core 0 (display, battery, storage), so slow work never delays input.
- Implemented `InputReader`:
  - All buttons are read in one go from the GPIO registers, with eager debounce.
  - `analogRead()` was measured at about 117 µs per read; the sticks now go through the ESP-IDF low-level ADC functions (a full scan takes about 160–180 µs).
  - Per-direction stick calibration and circular mapping brought the gamepad tester's circularity error from 15–19% down to **0.0%**.
  - Added a workaround for the ESP32 errata on GPIO36/39 (false LOW readings when the ADC powers up).
- Vendored ESP32-BLE-CompositeHID into `firmware/lib/` (the next upstream version needs ESP-IDF 5) and extended it: the full keyboard range including F13–F24, any media/consumer key, system keys (power, sleep, wake), and the device name in the scan response. Implemented `BleOutput`; all keys, mouse buttons 1–5, and both scroll directions verified on Windows.
- Implemented `Profiles` and `ProfileButton`: the four presets (GAMEPAD, KB+MOUSE, MEDIA, HYBRID with an R4 "PC layer"), up to 3 actions per button, Toggle/Turbo/Layer modes, stick modes, and the new profile button gestures (short press, double press, hold + A/B/X/Y). Verified on hardware, including WASD diagonals in a real game.
- Added `tools/InputTester.html`, a browser page that shows held keys, mouse buttons, scrolling, and gamepad buttons and sticks.
- Found that random power-offs and a right stick not resting at zero were caused by the ESP32 DevKit not being fully seated in its female headers (lost contact on the `5V` pin). Reseated the board; both problems disappeared.
- Implemented `Display` (switched from Adafruit SSD1306/GFX to U8g2, rotated 180°) and `BatteryMonitor` (MAX17048, battery level also reported to Windows). All on-device text is in English; profile names use one fixed font size.
- Implemented `Storage`: the controller starts on the last active profile. Enlarged the NVS settings store to 128 KB with a custom partition table. A first attempt that moved the app to 0x20000 boot-looped, because PlatformIO always flashes the app at 0x10000; the app stays at 0x10000 and NVS moved after it.
- Investigated the gamepad no longer working after a restart (Windows sometimes showing a phone or computer icon): the Bluetooth link came back, but the HID devices didn't. Added connection diagnostics, made room for more stored subscriptions, set the Bluetooth appearance to "gamepad", and count the controller as connected only once the link is encrypted. After one more re-pair, the controller has reconnected after every restart.
- Started the on-controller configuration menu (round 1): editing buttons, sticks, deadzones, and turbo speed, with Save / Discard / Keep editing when leaving.

## 2026-09-28 — Configuration Menu, Power Management and Firmware 1.0.0

- Finished the configuration menu (round 2): renaming (10 characters), new profiles from a preset or a copy, reordering and deleting profiles, and the Controller page (Forget Bluetooth, Reset all profiles, About). All verified on hardware, including after power cycles.
- Observed that right after **Forget Bluetooth**, the first pairing sometimes still doesn't survive a restart; one or two re-pairs fix it for good. The cause is not found yet; the debug build logs the stored pairings to investigate it.
- Added display settings: brightness (10 levels), screen timeout, and the profile name popup, previewed live in the menu.
- Found that the 10-second screen timeout never fired: at rest, the sticks jitter slightly past their deadzone. Sticks now count as activity only past 25% deflection.
- Added automatic power-off (separate times while connected and offline, default 5 minutes) with a 10-second full-screen countdown, plus a battery critical warning at 5% and automatic power-off at 2%. Experimentally verified that after the ESP32 enters deep sleep, the power module cuts the 5 V output completely, and that the on/off switch starts the controller again.
- Added **Recalibrate sticks** to the menu.
- Created the release and debug builds and tagged the firmware as **1.0.0**.
- Rewrote the repository documentation for the new firmware and added the User Guide.

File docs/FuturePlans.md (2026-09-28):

# Future Plans

Ideas and features being considered for after the first stable release (firmware 1.0.0). Nothing here is committed — this is a backlog of possibilities, not a roadmap with deadlines.

## Firmware

- Companion configuration tool (desktop or web-based) for managing profiles without using the on-device menu, and for backing up and sharing profiles.
- **Macros** (timed sequences of actions), configured through the companion tool: too fiddly to set up on the controller's small screen.
- Firmware OTA (over-the-air) update support.
- Find the cause of the occasional failed first pairing right after erasing the Bluetooth pairings (the debug build already logs the details).
- Measure the controller's current draw, to see whether light sleep between reports could save battery without making the power module cut the power.
- Verify the *Editing* (application commands) and *Brightness* consumer keys on Windows, and test other hosts (Android, Linux, macOS).

## Hardware

- Custom PCB to replace the protoboard assembly, reducing wiring complexity and improving reliability.
- Investigate alternative/additional joystick modules for comparison against the Ginfull hall-effect sticks.
- Analog triggers instead of the digital L2 / R2 buttons.
- Rumble/haptic feedback support, power budget permitting.

## Enclosure

- Iterate on the enclosure design beyond the current Alpakka-1-inspired shell, exploring ergonomic refinements specific to this hardware layout.
- Additional colorways/finishes for the 3D-printed shells.
- Finalize and publish the OLED/profile button suspended mounting platform as a proper 3D model.

## Documentation & Community

- Expand the Build Guide with step-by-step photos and wiring diagrams.
- Publish a demo video showing the profiles and the configuration menu in action.
- Open the project up for community-contributed enclosure variants (see [`CONTRIBUTING.md`](../CONTRIBUTING.md)).

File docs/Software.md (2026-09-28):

# Software / Firmware Architecture

## Toolchain

Firmware is developed using **PlatformIO** in VS Code — not the classic Arduino IDE. PlatformIO's real folder structure (`src/`, `include/`, `lib/`) maps naturally onto this project's modular design and works cleanly with Git version control, unlike the Arduino IDE's tab-based, folder-less sketches.

| Item | Version / Setting |
|---|---|
| Platform | `espressif32 @ 7.0.1` (Arduino core 2.0.17, ESP-IDF 4.4) |
| Board | `esp32dev` (ESP32-WROOM-32 DevKit) |
| Language | C++17 |
| Partition table | [`partitions.csv`](../firmware/partitions.csv): app 3 MB, NVS 128 KB |
| Libraries | Pinned to exact versions in [`platformio.ini`](../firmware/platformio.ini) |

The project has two builds of the same firmware:

* **`release`** (default) — what stays on the controller. No serial output.
* **`debug`** — adds `CONTROLLER_DEBUG`, which enables a timestamped serial log: stored Bluetooth pairings, connection and encryption results, disconnect reasons, battery readings, power decisions, and saves.

Build and flash instructions are in [`firmware/README.md`](../firmware/README.md).

## Core Library

The firmware is built on [ESP32-BLE-CompositeHID](https://github.com/Mystfit/ESP32-BLE-CompositeHID) (Mystfit fork), which enables native XInput support combined with simultaneous generic HID (keyboard/mouse) output over Bluetooth LE.

This replaces the earlier [ESP32-BLE-Gamepad](https://github.com/lemmingDev/ESP32-BLE-Gamepad) library (lemmingDev), which only supported DirectInput/generic HID gamepad output and required third-party workarounds like **x360ce** for compatibility with XInput-only games.

The library is **vendored** in [`firmware/lib/ESP32-BLE-CompositeHID/`](../firmware/lib/ESP32-BLE-CompositeHID/) at commit `032b064`, with local changes. The next upstream commit uses ESP-IDF 5-only functions and no longer builds on Arduino core 2.0.x. Every local change is marked `Local change` in the code and listed in the library's `VENDORED.md`:

* Keyboard: the full key range 0x00–0xE7 (F13–F24, international and language keys), instead of 0x00–0x65.
* Consumer control: an array of two 16-bit usages (any media, launch, browser, editing, or brightness key), instead of a fixed bitmask of 24 keys. It is also smaller: 25 bytes of report map instead of 78.
* A new System Control collection (power down, sleep, wake up).
* The device name is sent in the scan response, because it doesn't fit in the 31-byte advertising packet.
* The link counts as connected only once it is encrypted.
* Diagnostic log lines (debug build only).

Other libraries: [NimBLE-Arduino](https://github.com/h2zero/NimBLE-Arduino) 2.5.1 (Bluetooth LE stack), [U8g2](https://github.com/olikraus/u8g2) 2.36.18 (OLED), and the [SparkFun MAX1704x Fuel Gauge](https://github.com/sparkfun/SparkFun_MAX1704x_Fuel_Gauge_Arduino_Library) library 1.0.4.

---

## Bluetooth / BLE Architecture

### Why Native XInput Matters

Many modern games do not recognize generic HID/DirectInput gamepads at all. **Fortnite** is a well-known example — it requires XInput-compatible input and will not detect a DirectInput controller natively. Previously, DirectInput controllers needed a workaround like **x360ce** to translate their input into an XInput-compatible signal.

This project avoids that entirely by presenting the controller as a **native XInput device** over Bluetooth LE.

### Library

BLE communication and HID/XInput report generation is handled by [**ESP32-BLE-CompositeHID**](https://github.com/Mystfit/ESP32-BLE-CompositeHID) (Mystfit fork). This library supports composite HID descriptors, allowing the device to expose:

* A native XInput gamepad interface, **and**
* A generic keyboard/mouse HID interface

simultaneously, which is what makes the **KB+MOUSE**, **HYBRID**, and **MEDIA** profiles possible without re-pairing or switching BLE modes.

The controller identifies itself as an **Xbox Series X controller** (Microsoft's vendor and product IDs), so Windows binds its own XInput driver (`xinputhid`) exactly as it does for a real Xbox controller. The Xbox device must be the first device in the report map for this to work.

| Identity | Value |
|---|---|
| Device name | Robitza's ESP32 Gamepad |
| Manufacturer | Robitza Electrical Engineering |
| Appearance | Gamepad |
| Services | HID, Battery (level reported to the host), Device Information |

⚠️ The combined HID report map of all devices must stay within **512 bytes** (the size limit of one GATT attribute). The library only checks each device separately; above the limit, Windows shows a driver error (Code 10). The Xbox **One S** configuration plus keyboard, media keys and mouse needs about 546 bytes and fails. The Xbox **Series** configuration used here needs **474 bytes**. The debug build logs the total at boot.

### Migration from ESP32-BLE-Gamepad

The original firmware (`[0.1.0]`) was based on [**ESP32-BLE-Gamepad**](https://github.com/lemmingDev/ESP32-BLE-Gamepad) by lemmingDev, which only exposed a generic HID/DirectInput gamepad. This was a foundational limitation, since it could not be recognized natively by XInput-only games — hence the architectural migration to [**ESP32-BLE-CompositeHID**](https://github.com/Mystfit/ESP32-BLE-CompositeHID).

### Pairing & Reset

The controller pairs with **bonding** (the keys are stored on both sides), so the host reconnects by itself after every power-on. NimBLE keeps up to 3 bonds, stored in NVS separately from the profiles; the room for stored subscriptions was raised from 8 to 24 (`CONFIG_BT_NIMBLE_MAX_CCCDS`), because each host subscribes to 7 characteristics.

All pairings are erased with **Controller → Forget Bluetooth** in the configuration menu. The current connection is dropped at once and the controller advertises for a new pairing; the host must remove the old device and pair again.

### Report Handling

Profiles are no longer tied to a fixed report type: any button can send any action, so every profile can use every HID device at once.

| HID device | Report ID(s) | Carries |
|---|---|---|
| Xbox Series controller | 0x01–0x04 | Buttons, D-pad, two sticks (±32767), two triggers |
| Mouse | 0x20 | 5 buttons, movement, vertical and horizontal scroll |
| Keyboard | 0x40 | Modifiers + 6 keys, usages 0x00–0xE7 |
| Consumer control | 0x43 | 2 simultaneous media / launch / browser keys |
| System control | 0x44 | Power down, sleep, wake up |

* `send()` takes the complete desired state every input cycle. A device's report goes out **only when its part changed**, at most once every 3.75 ms per device (two per 7.5 ms connection event), so the newest state always wins and the link is never flooded.
* Mouse movement is accumulated as fractions of a count and sent as whole counts, so slow stick movements still move the cursor smoothly.
* Axis conventions are converted at the output: internally +Y means up; the Xbox and mouse reports use +Y = down.
* The controller requests a **7.5 ms** connection interval with no slave latency; Windows accepts it.
* While the configuration menu is open, the host receives a neutral report (nothing pressed, sticks centered).

### Known Limitations / Open Items

* Tested with **Windows 11** only.
* Right after **Forget Bluetooth** (or an Erase Flash), the first pairing sometimes doesn't survive a restart; one or two re-pairs fix it for good. The cause is unknown. The debug build logs the stored bonds at boot and the encryption result of every connection, to investigate if it comes back.
* Connecting costs one input cycle of about 22 ms (the pairing is written to flash). It happens only at connection time, outside gameplay.
* L2 / R2 are digital buttons, so the XInput triggers are either released or fully pressed.
* The Xbox Share button can be mapped, but games don't see it.
* The *Editing* (application commands such as Copy, Paste, Undo) and *Brightness* consumer keys have not been verified on Windows yet.

---

## Module Structure

Each firmware module follows a consistent `.h` / `.cpp` pairing convention:

* `include/ModuleName.h` — declarations and function signatures, plus a comment describing the module's behavior.
* `src/ModuleName.cpp` — full implementation. Private state lives in an anonymous namespace.

The one exception is `main.cpp`, which has no `.h` counterpart, since it acts as the central orchestrator tying all other modules together. Modules exchange plain data structures (`InputState`, `OutputReport`, `BatteryStatus`...) defined in `ControllerTypes.h` and `ProfileTypes.h`, and don't call each other directly.

Every pin, I²C address, timing, and threshold lives in [`Config.h`](../firmware/include/Config.h).

### Modules

| Module | Task | Responsibility |
|---|---|---|
| **`InputReader`** | input | Reads all buttons and sticks; debounce, stick calibration, circular mapping, deadzone. |
| **`ProfileButton`** | input | Profile button gestures (next, previous, jump, open menu). |
| **`Profiles`** | input | The four presets, the profile list, and the engine that turns inputs into outputs through the active profile. |
| **`BleOutput`** | input | Thin wrapper over ESP32-BLE-CompositeHID: sends XInput/HID reports, battery level, pairing reset. |
| **`ConfigMenu`** | UI | The configuration menu's logic; produces a text-only `MenuView` for the display. |
| **`ActionCatalog`** | UI | Named, grouped tables of every action the menu offers. |
| **`Display`** | UI | SSD1306 OLED: status screen, profile popup, menu, alerts, screen timeout. |
| **`BatteryMonitor`** | UI | MAX17048 fuel gauge: charge level and charging state. |
| **`PowerManager`** | UI | Decides when to show power alerts and when to power off. |
| **`Storage`** | UI | Profiles and settings in NVS. |

The two tasks are described in [`Architecture.md`](Architecture.md).

---

## Input Processing

`InputReader` runs every **1 ms** in the input task. A full scan takes about 160–180 µs.

* **Sticks** are on ADC1 (ADC2 can't be used together with Bluetooth). The Arduino `analogRead()` costs about 117 µs per read and the IDF driver about 48 µs, almost all of it driver overhead, so the firmware configures ADC1 once and then converts through the IDF low-level HAL (a few µs per conversion). Each axis is oversampled 4 times per scan.
* **Calibration:** at power-on, each stick's center is averaged over 64 samples. A center too far from mid-scale means the stick was touched, and the nominal center is used instead. Each direction (left, right, up, down) is scaled by its own span, so both ends reach full deflection even when the center isn't exactly in the middle. The centers can be measured again from the menu (**Recalibrate sticks**).
* **Circular mapping:** each axis saturates on its own, so diagonals would reach the corners of a square; the output is clamped to a circle. Measured circularity error in a gamepad tester: **0.0%** (15–19% with plain per-axis mapping).
* **Deadzone:** radial, per stick and per profile (default 5%, up to 50%). Movement is rescaled so the output starts from 0 right at the deadzone edge instead of jumping.
* **Buttons** are read in one go from the two GPIO input registers, after the stick conversions so they are as fresh as possible. **Eager debounce:** a press counts on the first sample, then that pin is ignored for 5 ms — no added latency.
* **ESP32 errata (GPIO36 / GPIO39):** these pins can glitch LOW for about 80 ns when the ADC powers up. The firmware keeps the ADC powered permanently, samples the buttons only after all conversions have finished, and requires two consecutive LOW samples on these two pins.

---

## Profile Engine

A profile holds:

* A name (up to 10 characters).
* Two layers — the base layer and the **RTZ** layer — each with a mapping for all 17 mappable buttons and both sticks.
* Per button: up to **3 actions**, fired together, and a mode (**Normal**, **Toggle**, **Turbo**).
* Per stick: a mode (**None**, **Xbox left**, **Xbox right**, **Mouse**, **Scroll**, **4-way**), a speed (1–10), and 4 direction actions for 4-way mode.
* A deadzone per stick and a turbo speed (1–20 Hz).

An action is one of: Xbox button, D-pad direction, trigger, keyboard key, consumer key, system key, mouse button, scroll step, or **RTZ layer**. The Profile button itself can't be mapped.

`Profiles::apply()` is called once per input cycle and turns the `InputState` into an `OutputReport`:

* **Layers:** a button whose action is *RTZ layer* activates the second layer while held (Toggle mode latches it). Each press keeps the layer it started on, so a layer change can't leave a key stuck.
* **Mouse:** speed follows the stick deflection through a curve (deflection²), precise near the center and fast at full deflection; sensitivity 5 is 1500 counts/s at full deflection.
* **Scroll:** 4 steps/s per sensitivity step at full deflection. A button mapped to a scroll direction scrolls once, then repeats after 300 ms while held.
* **4-way:** a direction presses at 50% deflection and releases below 35%, so it can't chatter at the threshold; diagonals press two directions.
* **Profile switch:** toggles, turbo, and layers are reset, and buttons still held from the previous profile stay silent until released, so a switch never fires the new profile's actions by itself.

---

## Profile State Machine

Handled by `ProfileButton.cpp`, driven by the profile button on GPIO36:

* Short press → next profile (after 300 ms, to tell it apart from a double press).
* Double press → back to the previously active profile.
* Hold + A / B / X / Y → jump to profile 1 / 2 / 3 / 4.
* Hold for 3 s with nothing else pressed → open the configuration menu.

Buttons pressed while the profile button is held are kept from the host until they are released.

The **configuration menu** (`ConfigMenu`) replaces the earlier L4/R4 press-to-bind design: every button and stick of every profile can be changed on the controller, and the button to edit is chosen by pressing it. It runs in the UI task and edits a copy of the profile list and of the controller settings; the copy replaces the real one only when the user chooses **Save** on the way out. The menu is described in detail in the [User Guide](UserGuide.md).

---

## Persistence

All profiles and settings are stored using the ESP32's **NVS (Non-Volatile Storage) / Preferences API**, so settings survive power cycles. Everything lives in the NVS namespace `controller`:

| Key | Contents |
|---|---|
| `p0` … `p15` | One profile per slot |
| `count` | Number of saved profiles |
| `format` | Layout version of the saved profiles (`PROFILE_FORMAT_VERSION`) |
| `active` | The last active profile |
| `display` | Brightness, screen timeout, name popup |
| `power` | Automatic power-off times |

* **When it writes:** profiles and settings only when the user saves in the menu (only the changed slots, then the count); the active profile once it has stayed selected for 3 seconds. Never from the input task: a flash write briefly stalls both CPU cores.
* **Validation:** every stored value is checked when loaded; a missing or damaged value falls back to the defaults, or to the four presets for the profile list.
* **Format changes:** saved profiles carry a format version. A firmware with a different profile layout ignores them and the presets come back, unless a migration for that version is added to `Storage`.
* The Bluetooth pairings are stored by NimBLE in its own NVS namespace, which is why **Reset all profiles** keeps them.

---

## Power Management

`PowerManager` runs in the UI task. It only decides; `main.cpp` shows the alerts and runs the shutdown.

* **Automatic power-off:** after the configured time without activity (separate settings for connected and not connected; 1–60 minutes or never, default 5 minutes), with a 10-second full-screen countdown that any activity cancels. Activity means any button, or a stick past 25% deflection; at rest a stick can jitter just past its deadzone, which must not keep the controller on.
* **Battery critical:** at 5% or less (not charging), a full-screen warning for 5 seconds, repeated every minute.
* **Battery empty:** at 2% or less in 3 readings in a row (not charging), a short message, then power-off to protect the Li-Po cell.

The firmware can't disconnect the battery, and it can't switch the controller back on. It powers off by entering **deep sleep** with no wake-up source: the input task stops sending, the OLED is switched off, the Bluetooth connection is closed (so the host sees the controller leave at once), and the ESP32 sleeps. The load then falls far below the power module's minimum, and the module switches its 5 V output off about 30 seconds later. The on/off switch restarts the controller.

Light sleep and CPU down-clocking are deliberately not used while the controller is on: with less current draw, the power module would switch the controller off in the middle of use.

---

## Legacy Bugs Fixed (from the [0.1.0] firmware)

The original lemmingDev-based firmware had several issues, all fixed by the rewrite:

* Incorrect joystick axis mapping (0 → 32767 instead of the correct signed range, -32767 → 32767) — the axes are now signed and calibrated per direction.
* Deadzone value declared but never actually applied — the radial deadzone is applied to every stick.
* Blocking `delay()` calls in the main loop — no blocking calls; the input task runs on a fixed 1 ms schedule.
* No button debounce — eager debounce on every button.
* Insufficient error handling for a missing/disconnected battery sensor — the firmware keeps running without the fuel gauge or the display.

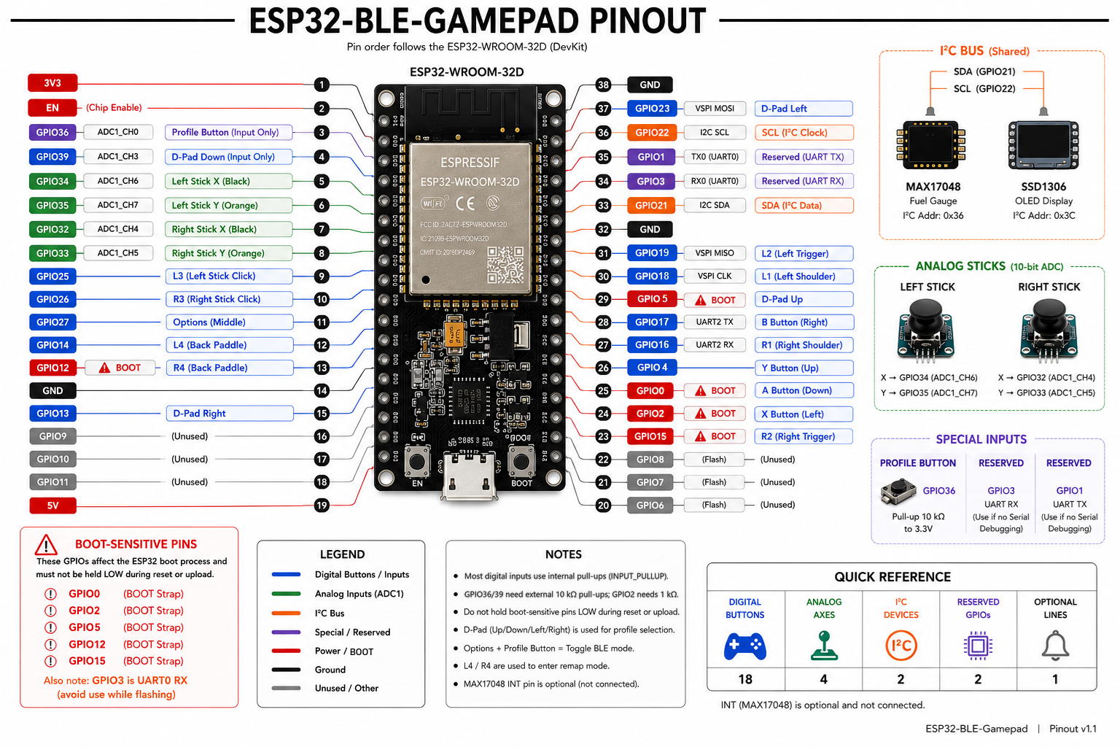
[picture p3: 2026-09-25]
hardware/pinout/Pinout.png

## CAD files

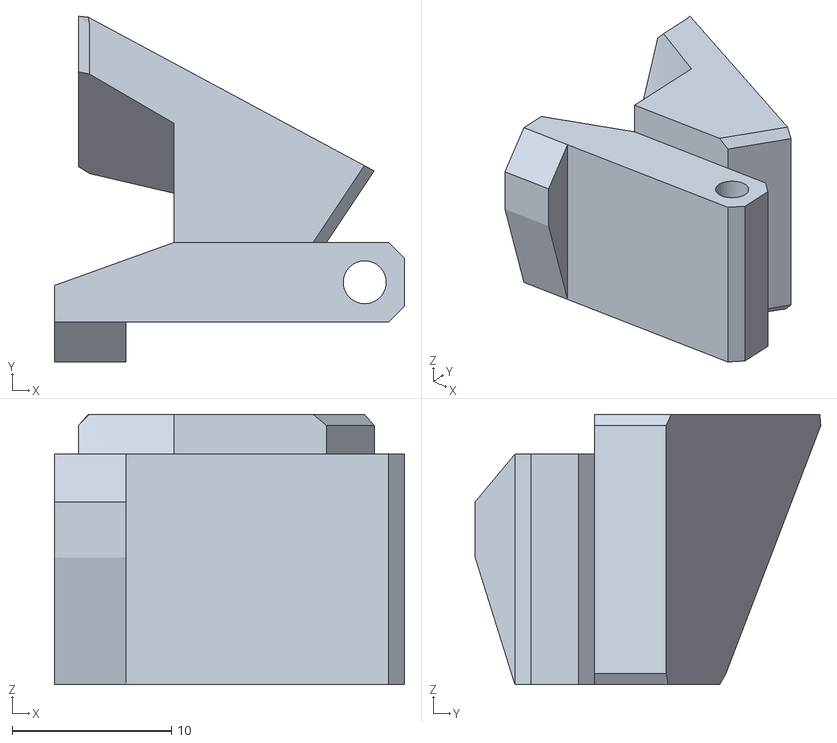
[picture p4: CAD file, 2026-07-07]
enclosure/stl/black_R4.stl
22.0 x 21.7 x 17.0

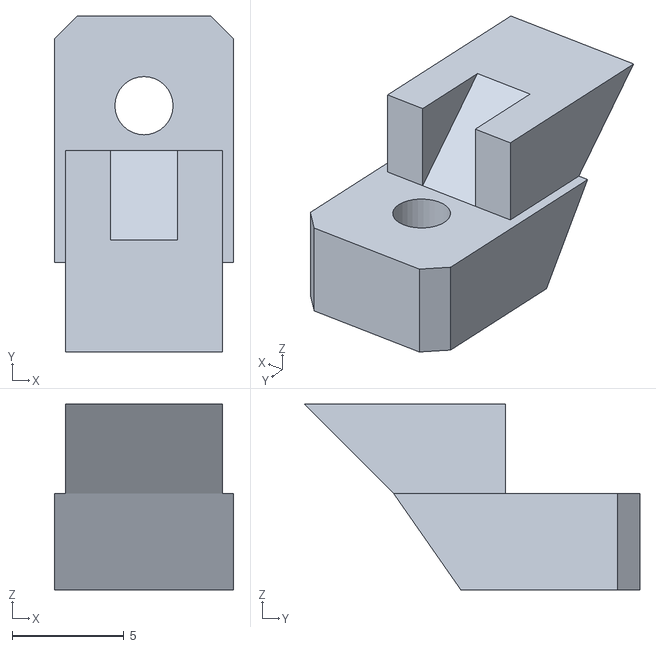
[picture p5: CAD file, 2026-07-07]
enclosure/stl/black_anchors.stl
8.00 x 15.0 x 8.30

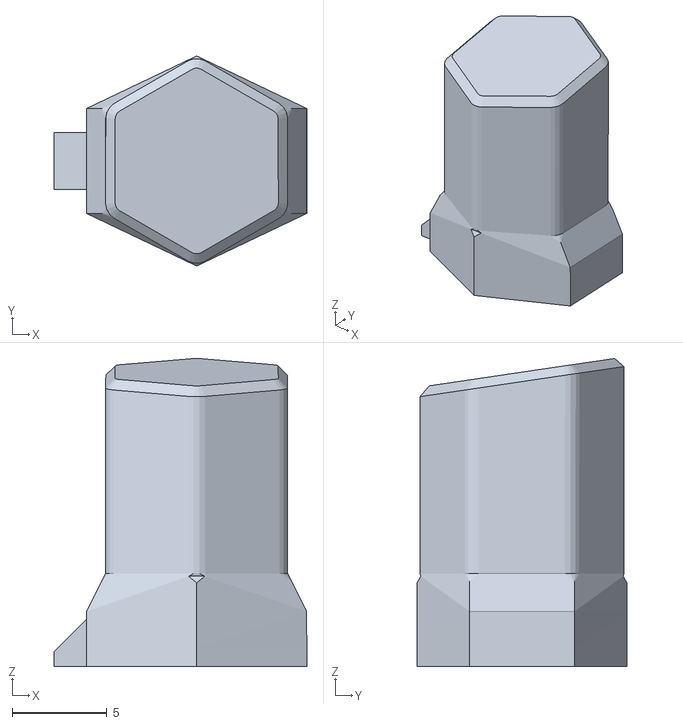
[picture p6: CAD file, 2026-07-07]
enclosure/stl/green_home.stl
13.3 x 11.1 x 16.2

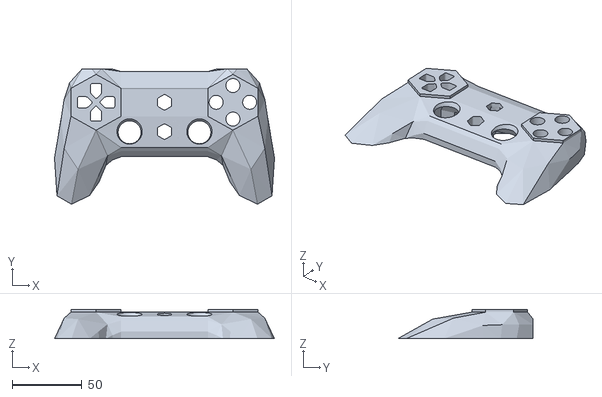
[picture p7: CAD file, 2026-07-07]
enclosure/stl/black_front.stl
157.6 x 97.0 x 21.0

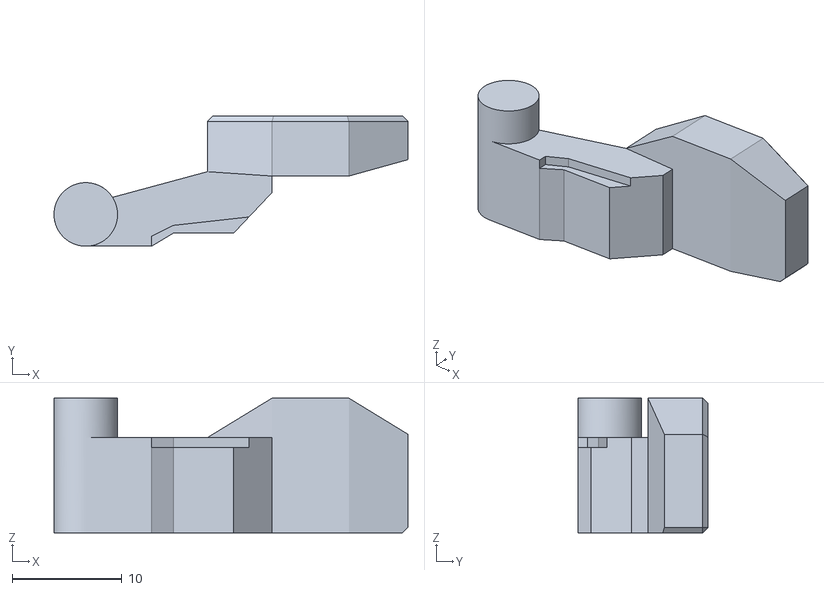
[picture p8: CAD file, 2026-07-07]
enclosure/stl/black_R1.stl
32.3 x 11.9 x 12.3

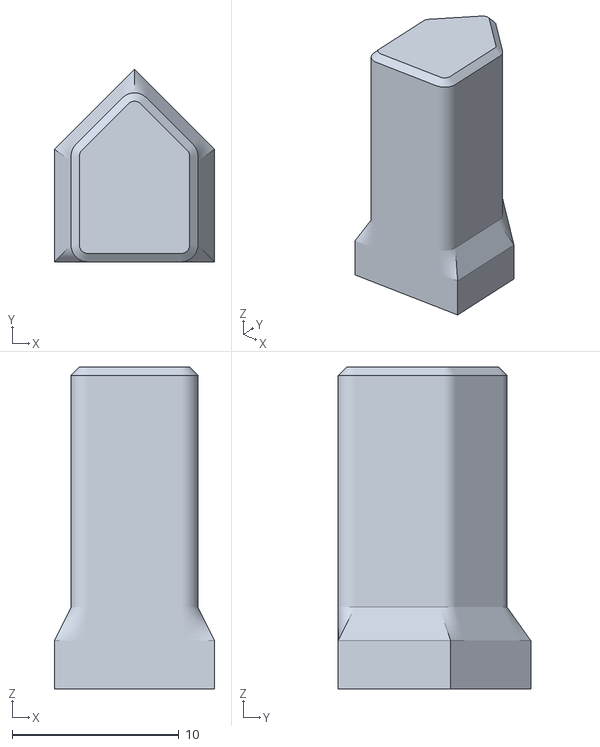
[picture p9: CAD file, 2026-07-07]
enclosure/stl/green_dpad_x4.stl
9.60 x 11.5 x 19.3

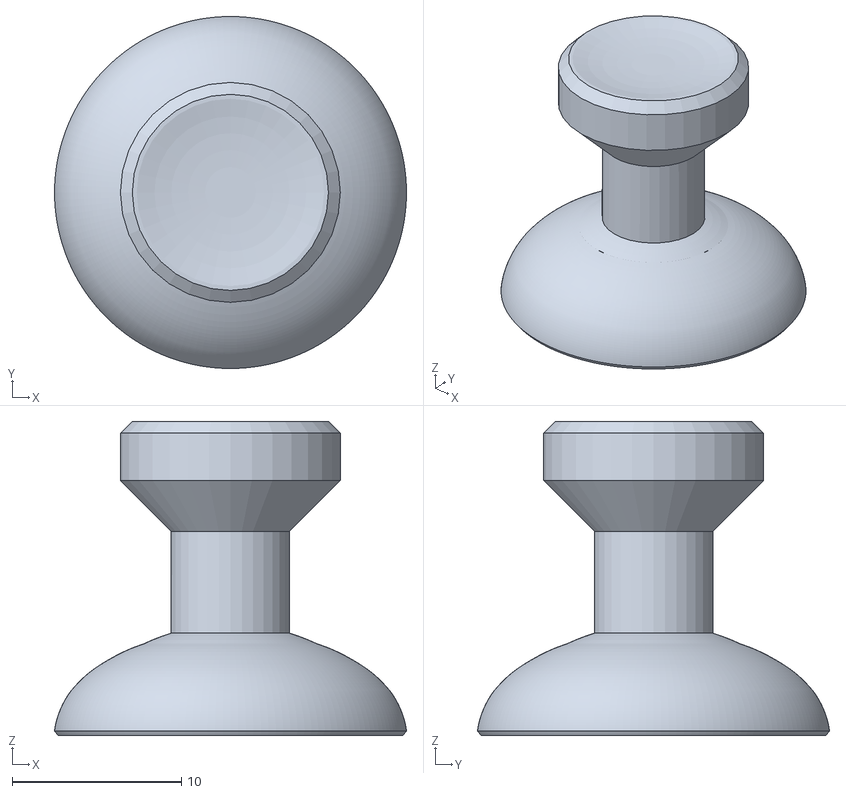
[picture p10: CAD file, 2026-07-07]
enclosure/stl/green_thumbstick_x2.stl
20.8 x 20.8 x 18.6

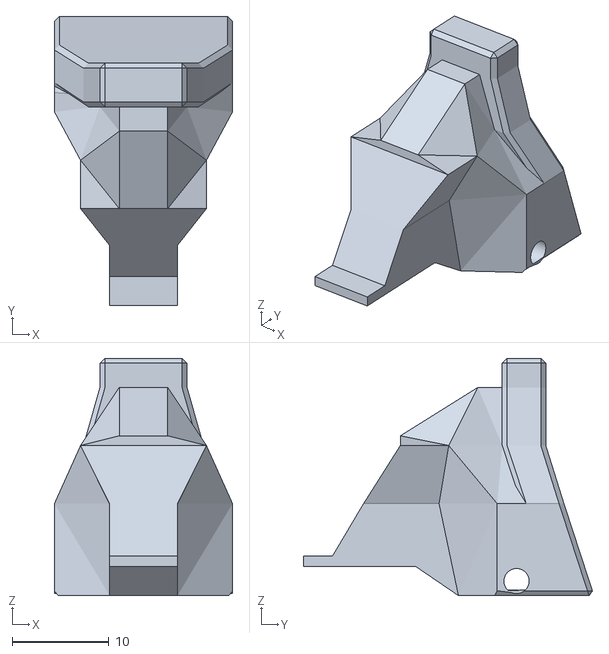
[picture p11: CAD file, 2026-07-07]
enclosure/stl/black_R2.stl
18.4 x 29.8 x 24.5

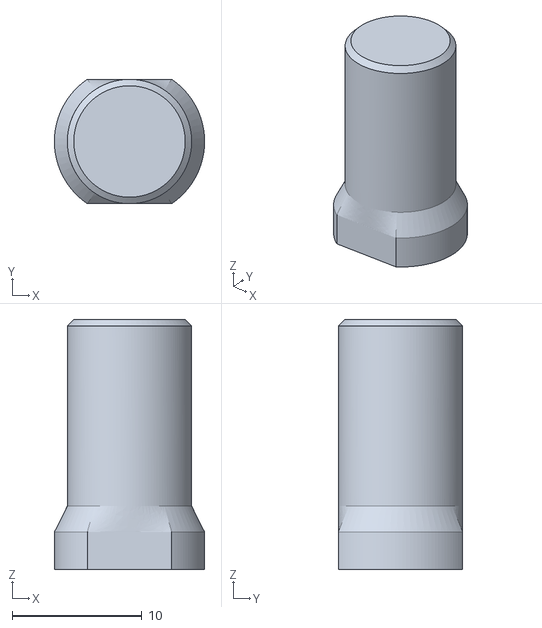
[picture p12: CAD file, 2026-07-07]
enclosure/stl/green_abxy_x4.stl
11.6 x 9.60 x 19.3

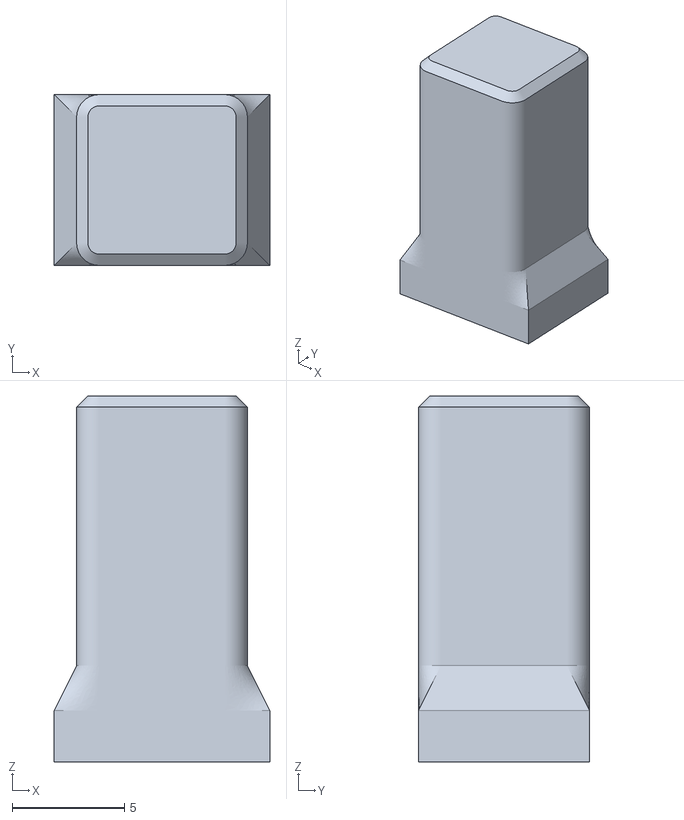
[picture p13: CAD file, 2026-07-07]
enclosure/stl/green_on_off.stl
9.60 x 7.60 x 16.3

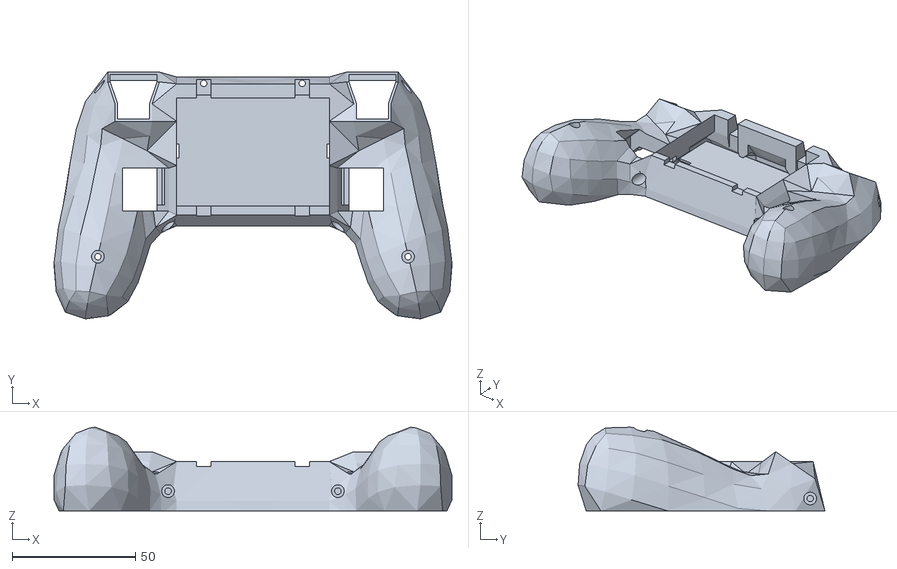
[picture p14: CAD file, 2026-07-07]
enclosure/stl/green_back.stl
161.7 x 100.3 x 34.0

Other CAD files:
enclosure/stl/black_L4.stl
enclosure/stl/black_L1.stl
enclosure/stl/black_L2.stl

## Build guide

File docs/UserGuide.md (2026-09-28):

# User Guide

How to use the controller with firmware **1.0.0**: switching it on and off, pairing, the status screen, profiles, the configuration menu, and what to do when something doesn't work.

---

## Controls

| Control | Location |
|---|---|
| A / B / X / Y | Face buttons (down / right / left / up) |
| D-pad | Up / Down / Left / Right |
| L1 / R1 | Shoulder buttons |
| L2 / R2 | Triggers (digital: either released or fully pressed) |
| L3 / R3 | Stick clicks |
| L4 / R4 | Back paddles |
| Options | Middle button |
| Profile | Square button next to the screen: switches profiles and opens the configuration menu |
| On/off switch | Square button next to the screen: switches the power on and off |

What each button does depends on the active profile (see [Built-in Presets](#built-in-presets)). Only the **Profile** button is fixed.

---

## Turning On and Off

* **On:** press the on/off switch. Keep your hands off the sticks for the first moment: the controller measures their resting position at power-on. Don't hold any button while switching on, since several buttons sit on ESP32 boot pins.
* **Off:** press the on/off switch again. It cuts the power immediately, so unsaved changes in the configuration menu are lost.
* **Automatic power-off:** after a period without input (5 minutes by default) the controller counts down for 10 seconds and switches itself off. Any button cancels the countdown. See [Power and Battery](#power-and-battery).
* **After an automatic power-off**, the on/off switch is still in the "on" position: switch it off, then on again.

---

## Pairing

The controller has been tested with **Windows 11**.

1. Switch the controller on.
2. In Windows, open **Settings → Bluetooth & devices → Add device → Bluetooth**.
3. Select **Robitza's ESP32 Gamepad**.

Windows installs it as an Xbox controller, a keyboard and a mouse at once. From then on, the controller reconnects by itself every time it is switched on, and its battery level is shown next to it in the Bluetooth settings.

To pair it from scratch, use **Controller → Forget Bluetooth** in the configuration menu, then remove the controller from the Windows Bluetooth list and pair it again.

---

## Status Screen

```
 ᛒ connected          ⚡ 78% [▮▮▮▯]

             GAMEPAD
              1 / 4
                                 RTZ
```

* **Top left:** Bluetooth status, `connected` or `disconnected`.
* **Top right:** battery percentage and a 4-bar indicator. A lightning bolt appears while charging (it can take a minute or two to show up after plugging in the charger).
* **Middle:** the name of the active profile and its position in the profile list.
* **Bottom right:** `RTZ` while the RTZ layer is active, `TOGGLE` while a Toggle-mode button is switched on.

After a profile switch, the new profile's name is shown full screen for about a second. The screen switches off after 30 seconds without input (adjustable in **Controller → Display**). Any button, or a stick pushed past about a quarter of its travel, wakes it up; small stick movements are ignored.

---

## Profile Button

| Gesture | Result |
|---|---|
| Short press | Next profile |
| Double press | Back to the previous profile (repeat to toggle between the two) |
| Hold Profile + press A / B / X / Y | Jump to profile 1 / 2 / 3 / 4 |
| Hold for 3 seconds (nothing else pressed) | Open the configuration menu |

Buttons pressed while the Profile button is held are never sent to the computer, so the shortcuts can't trigger anything in a game.

The controller remembers the active profile and starts on it after the next power-on.

---

## Built-in Presets

On first boot the profile list contains one profile per preset, in the order of the table: GAMEPAD is profile 1, HYBRID is profile 4. The presets also serve as templates for new profiles, and **Reset all profiles** brings this list back.

| Input | GAMEPAD | KB+MOUSE | MEDIA | HYBRID: RTZ layer (R4 held) |
|---|---|---|---|---|
| A | Xbox A | Space | Left click | Enter |
| B | Xbox B | Left Ctrl | Right click | Esc |
| X | Xbox X | R | Middle click | — |
| Y | Xbox Y | E | Enter | — |
| D-pad Up | D-pad Up | 1 | Volume + | Volume + |
| D-pad Right | D-pad Right | 2 | Next track | Next track |
| D-pad Down | D-pad Down | 3 | Volume − | Volume − |
| D-pad Left | D-pad Left | 4 | Previous track | Previous track |
| L1 | LB | Q | Mouse Back | — |
| R1 | RB | F | Mouse Forward | — |
| L2 | LT | Right click | Alt+Tab | Right click |
| R2 | RT | Left click | Win+D | Left click |
| L3 | Left stick click | Left Shift | Mute | — |
| R3 | Right stick click | V | Esc | — |
| L4 | View | Tab | Ctrl+C | — |
| R4 | Xbox Guide | M | Ctrl+V | *held: activates this layer* |
| Options | Menu | Esc | Play / Pause | Play / Pause |
| Left stick | Xbox left stick | W / A / S / D | Mouse | Scroll |
| Right stick | Xbox right stick | Mouse | Scroll | Mouse |

* **GAMEPAD** — a regular Xbox controller. The controller has only one middle button, so View and the Guide button sit on the back paddles.
* **KB+MOUSE** — for PC games without controller support (FPS layout).
* **MEDIA** — for using the computer from the couch.
* **HYBRID** — works exactly like GAMEPAD, except for R4: while R4 is held, the controller switches to the layer in the last column, to operate the computer without leaving the game profile. A dash (—) means the button does nothing while the layer is active.

All presets start with a 5% stick deadzone, a turbo speed of 10 presses per second and a mouse / scroll speed of 5.

---

## Profiles

The controller holds up to **16 profiles**, each with a name of up to 10 characters. Everything in a profile can be changed in the configuration menu:

* **Actions** — each button sends up to three actions at the same time (for example Ctrl + C, or LB + RB, or an Xbox button plus a keyboard key). Actions come from these lists:

  | List | Contents |
  |---|---|
  | None | The button does nothing |
  | RTZ layer | Activates the RTZ layer (see below) |
  | Gamepad | A, B, X, Y, LB, RB, LT, RT, View, Menu, Guide, Share, stick clicks, D-pad |
  | Keyboard | Letters, Numbers, F1–F24, Modifiers, Navigation, Basic keys, Symbols, Numpad, Other (every remaining key) |
  | Mouse | Left, Right, Middle, Back, Forward, scroll up / down / left / right |
  | Media & system | Media & volume, Launch apps (media player, mail, calculator, File Explorer), Browser, Editing, Brightness, System (power down, sleep, wake up) |

  Share is available, but games don't see it. The *Editing* keys (Copy, Paste, Undo...) only work in applications that support them, and the *Brightness* keys only on laptops and displays that support them.
* **Button mode** — **Normal** (the actions follow the button), **Toggle** (one press switches the actions on, the next one off) or **Turbo** (while held, the actions repeat at the profile's turbo speed, 1–20 per second).
* **RTZ layer** ("Robitza-Shift") — every profile has a second set of mappings, the RTZ layer. A button set to *RTZ layer* activates it while held; in Toggle mode, it locks the layer on until the next press. On the RTZ layer, *None* means the button is disabled while the layer is active.
* **Stick mode** — *Xbox L*, *Xbox R*, *Mouse*, *Scroll* (vertical and horizontal), *4-way* (each direction sends its own actions, for example W / A / S / D or the arrow keys) or *None*. Mouse and Scroll have a speed setting (1–10); the mouse moves slowly near the center for precision and fast at full deflection.
* **Deadzone** — per stick, 0–50%. Stick movement inside the deadzone is ignored.

---

## Configuration Menu

Hold the **Profile** button for 3 seconds to open the menu. While the menu is open, the computer receives no input from the controller.

### Navigation

| Control | Action |
|---|---|
| D-pad / left stick | Move the cursor (held: repeats; the stick repeats faster the further it's pushed) |
| Left / Right | Change a value shown as `< value >` |
| A | Open / select |
| B | Back |
| L1 / R1 | Jump a page in long lists |
| Profile (short press) | Back |
| Profile (hold 3 s) | Leave the menu |

* A `>` at the end of a row opens a page; a row showing a value opens a list of choices.
* In a list, `*` marks the current choice.
* A fresh press at the end of a list wraps around to the other end; a held direction stops at the end.
* If the screen is off, the first press only wakes it up.

### Menu Pages

```
MENU
├── Edit <profile>
│   ├── Buttons ........... press the button to edit → Layer, Action 1–3, Mode
│   ├── Left stick ........ Layer, Mode, Speed or the 4 direction actions
│   ├── Right stick ....... Layer, Mode, Speed or the 4 direction actions
│   ├── Deadzone L / R .... 0–50%
│   ├── Turbo speed ....... 1–20 Hz
│   ├── Rename
│   └── Copy base to RTZ .. replaces the RTZ layer with a copy of the base layer
├── New profile ........... from a preset or a copy of a profile, then name it
├── Profiles .............. pick one → Edit, Move up, Move down, Delete
├── Controller
│   ├── Display ........... Brightness 1–10, Screen off, Name popup
│   ├── Auto off .......... Connected, Offline
│   ├── Recalibrate sticks
│   ├── Forget Bluetooth
│   ├── Reset all profiles
│   └── About ............. firmware version
└── Exit
```

* **Edit** always opens on the active profile. To edit another one, pick it on the **Profiles** page.
* **Buttons:** press the button you want to edit on the controller itself. On this screen B is also a button you may want to edit, so a short press of **Profile** goes back.
* **Layer** (on the button and stick pages) switches between the base layer and the RTZ layer; the rows below show the selected layer.
* **New profile** becomes the active profile and opens its Edit page. There is room for 16 profiles.
* **Delete** asks for confirmation. The last remaining profile can't be deleted.
* **Display** changes are shown immediately, so you can see the brightness while adjusting it.
* **Recalibrate sticks:** let go of both sticks, then press A. Useful if a stick was touched while the controller was switched on.
* **Forget Bluetooth** erases all pairings immediately (after a confirmation). Remove the controller in Windows and pair it again.
* **Reset all profiles** replaces every profile with the four presets.

### Entering a Name

| Control | Action |
|---|---|
| Up / Down | Change the character under the cursor |
| Left / Right | Move the cursor |
| L1 / R1 | Jump to the previous / next character group (A–Z, a–z, 0–9, symbols) |
| X | Delete the character (the rest moves left) |
| Y | Insert a space |
| A | Done |
| B | Cancel |

An empty name becomes `PROFILE`.

### Saving

All changes are made on a copy. When you leave the menu (hold **Profile** for 3 seconds, or select **Exit**) and something has changed, the menu asks **Save changes?**:

* **A** — save and leave.
* **B** — discard the changes and leave.
* **Profile** — keep editing.

Deleting a profile and resetting all profiles are also only kept if you save. **Forget Bluetooth** and **Recalibrate sticks** take effect immediately.

---

## Power and Battery

### Automatic Power-Off

**Controller → Auto off** sets how long the controller waits without input before switching itself off:

* **Connected** — while connected to a computer.
* **Offline** — while not connected.

Each can be 1, 2, 3, 5, 10, 15, 30 or 60 minutes, or **Never**. Both are 5 minutes by default.

Any button counts as input, including a button that is held down (for example a held accelerator in a racing game). A stick only counts when pushed past about a quarter of its travel, so a stick resting slightly off-center doesn't keep the controller awake.

During the last 10 seconds, the screen shows a countdown; any button cancels it. The power-off also happens while the menu is open, in which case unsaved changes are lost.

When it powers off, the controller disconnects from the computer, switches the screen off and goes to sleep. About 30 seconds later the power module cuts the power completely, so the battery is not drained. To switch the controller on again, switch it off and on with the on/off switch.

### Battery Warnings

* **5% or less:** a full-screen *Battery critical* warning for a few seconds, repeated every minute. Charge the controller.
* **2% or less:** a *Battery empty* message, then the controller switches itself off to protect the battery.

Neither happens while the controller is charging.

---

## Troubleshooting

| Problem | Solution |
|---|---|
| The controller doesn't switch on after an automatic power-off | Switch it off, then on again with the on/off switch. |
| Connected, but the gamepad doesn't work, or Windows shows a phone or computer icon | Remove the controller in the Windows Bluetooth settings and pair it again. Right after **Forget Bluetooth**, it can take one or two re-pairs before the pairing sticks. |
| A browser gamepad tester doesn't see the controller after re-pairing | Reload the page: Windows creates a new device after a re-pair. |
| A stick drifts or doesn't rest at zero | Use **Controller → Recalibrate sticks** with both sticks released, or switch the controller off and on without touching the sticks. |
| The screen doesn't switch off | A button is being held (for example pressed by the charging cable or the enclosure). |
| The controller switches off or restarts randomly | Check that the ESP32 board is pushed fully into its headers: a loose 5 V pin causes exactly this. |
| Something else | Flash the debug build and read the serial log (see [`firmware/README.md`](../firmware/README.md)). |

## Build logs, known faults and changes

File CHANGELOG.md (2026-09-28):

# Changelog

All notable changes to this project will be documented in this file.

The format is based on [Keep a Changelog](https://keepachangelog.com/en/1.1.0/),
and this project adheres to [Semantic Versioning](https://semver.org/spec/v2.0.0.html).

## [Unreleased]

---

## [1.0.0] - 2026-09-28

Complete rewrite of the firmware as a modular PlatformIO project. Tested on the real hardware with Windows 11.

### Added
- Migration to **ESP32-BLE-CompositeHID** (Mystfit fork) for native XInput support combined with simultaneous keyboard/mouse HID. The controller appears as an Xbox Series X controller named **Robitza's ESP32 Gamepad**.
- Keyboard (full key range, including F13–F24 and the numpad), 5-button mouse with vertical and horizontal scrolling, media / launch / browser keys, and system keys (power down, sleep, wake up), all on the same Bluetooth connection.
- Battery level reported to the host (shown in the Windows Bluetooth settings).
- **Profile system** with up to 16 profiles, starting from four built-in presets:
  - **GAMEPAD** — pure XInput; L4 = View, R4 = Guide.
  - **KB+MOUSE** — FPS layout: left stick as WASD, right stick as mouse, R2 / L2 as left / right click, the other buttons as keys.
  - **MEDIA** — mouse, scrolling, volume and track control, play/pause, Alt+Tab, Win+D, copy and paste.
  - **HYBRID** — GAMEPAD, plus a PC layer while R4 is held (mouse, scroll, clicks, Enter / Esc, media keys).
- Up to 3 simultaneous actions per button; button modes Normal, Toggle, and Turbo (1–20 Hz).
- **RTZ layer** ("Robitza-Shift"): a second set of mappings in every profile, activated by a button while held or latched in Toggle mode.
- Stick modes: Xbox left, Xbox right, mouse (with a response curve), scroll, 4-way (one action per direction), or none; per-stick deadzone and speed.
- Profile button gestures (GPIO36): short press = next profile, double press = previous profile, hold + A/B/X/Y = jump to profile 1–4, hold 3 s = configuration menu.
- **On-controller configuration menu** on the OLED: edit any button (chosen by pressing it) or stick on both layers, deadzones, turbo speed, rename; create profiles from a preset or a copy; reorder and delete profiles; controller settings. Changes are saved only on explicit Save.
- OLED status display (SSD1306, I2C): Bluetooth state, battery percentage with 4 bars and a charging indicator, active profile name and number, RTZ / TOGGLE tags, and a full-screen popup after a profile switch.
- Display settings: brightness (10 levels), screen timeout (10 s to 5 min, or never), profile name popup on/off.
- Dedicated battery fuel gauge (MAX17048) for accurate state-of-charge, independent of the power management chip.
- **Automatic power-off** after a configurable time without input (separately for connected and offline; 1–60 minutes or never, default 5 minutes), with a 10-second on-screen countdown. Uses ESP32 deep sleep, after which the power module switches the 5 V output off.
- Battery protection: full-screen warning at 5%, automatic power-off at 2%.
- Stick calibration: per-direction scaling around the center measured at power-on, circular output (0% circularity error), radial deadzone; the centers can be measured again from the menu.
- Persistent storage in NVS: profiles, the last active profile (restored at power-on), display and power settings.
- Forget Bluetooth pairings from the menu.
- Release and debug builds; the debug build adds a serial log (pairing, connection, battery, power, saves).
- `tools/InputTester.html`: a browser page showing held keys, mouse buttons, scrolling, and gamepad buttons and sticks, to test every output.
- Full modular firmware structure (separate modules for input, profiles, profile button, configuration menu, BLE output, display, battery, power, and storage).

### Changed
- Project migrated from Arduino IDE to **PlatformIO** for proper modular folder structure and version control.
- Input scanning runs at a fixed 1 kHz in its own task on a dedicated CPU core; display, battery, and storage work runs on the other core.
- Reports are sent only when the state changes, with a requested 7.5 ms Bluetooth connection interval.
- OLED library changed from Adafruit SSD1306/GFX to U8g2.
- Custom partition table with a 128 KB settings store (NVS).
- The profile button design changed from "hold 0.5 s to arm, D-pad to select, press L4/R4 to remap" to direct gestures plus a full configuration menu, where every button can be remapped.
- Power management uses deep sleep for automatic power-off instead of the planned light sleep, which would make the power module cut the power during use.
- Legacy sketches (`Code.ino`, `Code(Experimental).ino`, `Test Code/`) removed; they remain available in the Git history.

### Fixed
- Joystick axis mapping corrected to signed range (-32767 to 32767) instead of unsigned (0 to 32767).
- Deadzone logic now actually applied (previously declared but unused).
- Removed blocking `delay()` calls from the main loop.
- Added button debounce (eager: no added latency).
- Corrected pin assignments to match physical hardware (previously inconsistent in the "stable" firmware variant).
- Safer battery sensor initialization to prevent crashes when the sensor is absent; the firmware also keeps running without the display.
- Correct fuel gauge scaling: the driver is set to the MAX17048 (the library defaults to the MAX17043).
- ESP32 errata on GPIO36/39 (false presses when the ADC powers up) handled in firmware.

### Known Issues
- Right after erasing the Bluetooth pairings, the first pairing sometimes doesn't survive a restart; one or two re-pairs fix it.
- The *Editing* and *Brightness* consumer keys have not been verified on Windows yet.

---

## [0.1.0] - 2026-07-06

First functional version of the controller, based on the [ESP32-BLE-Gamepad](https://github.com/lemmingDev/ESP32-BLE-Gamepad) library by lemmingDev.

### Added
- Initial BLE gamepad functionality using ESP32-BLE-Gamepad.
- Basic joystick and button input reading.
- Basic battery voltage reading.

### Known Issues
- Uses ESP32-BLE-Gamepad (DirectInput/generic HID), not XInput — controller is not natively recognized by modern games (e.g. Fortnite) without third-party workarounds.
- Joystick axis mapping outputs unsigned range (0 to 32767) instead of signed (-32767 to 32767).
- Deadzone variable declared but never applied.
- Blocking `delay()` calls used in the main loop.
- No button debounce implemented.
- No fallback handling when the battery sensor is not detected.

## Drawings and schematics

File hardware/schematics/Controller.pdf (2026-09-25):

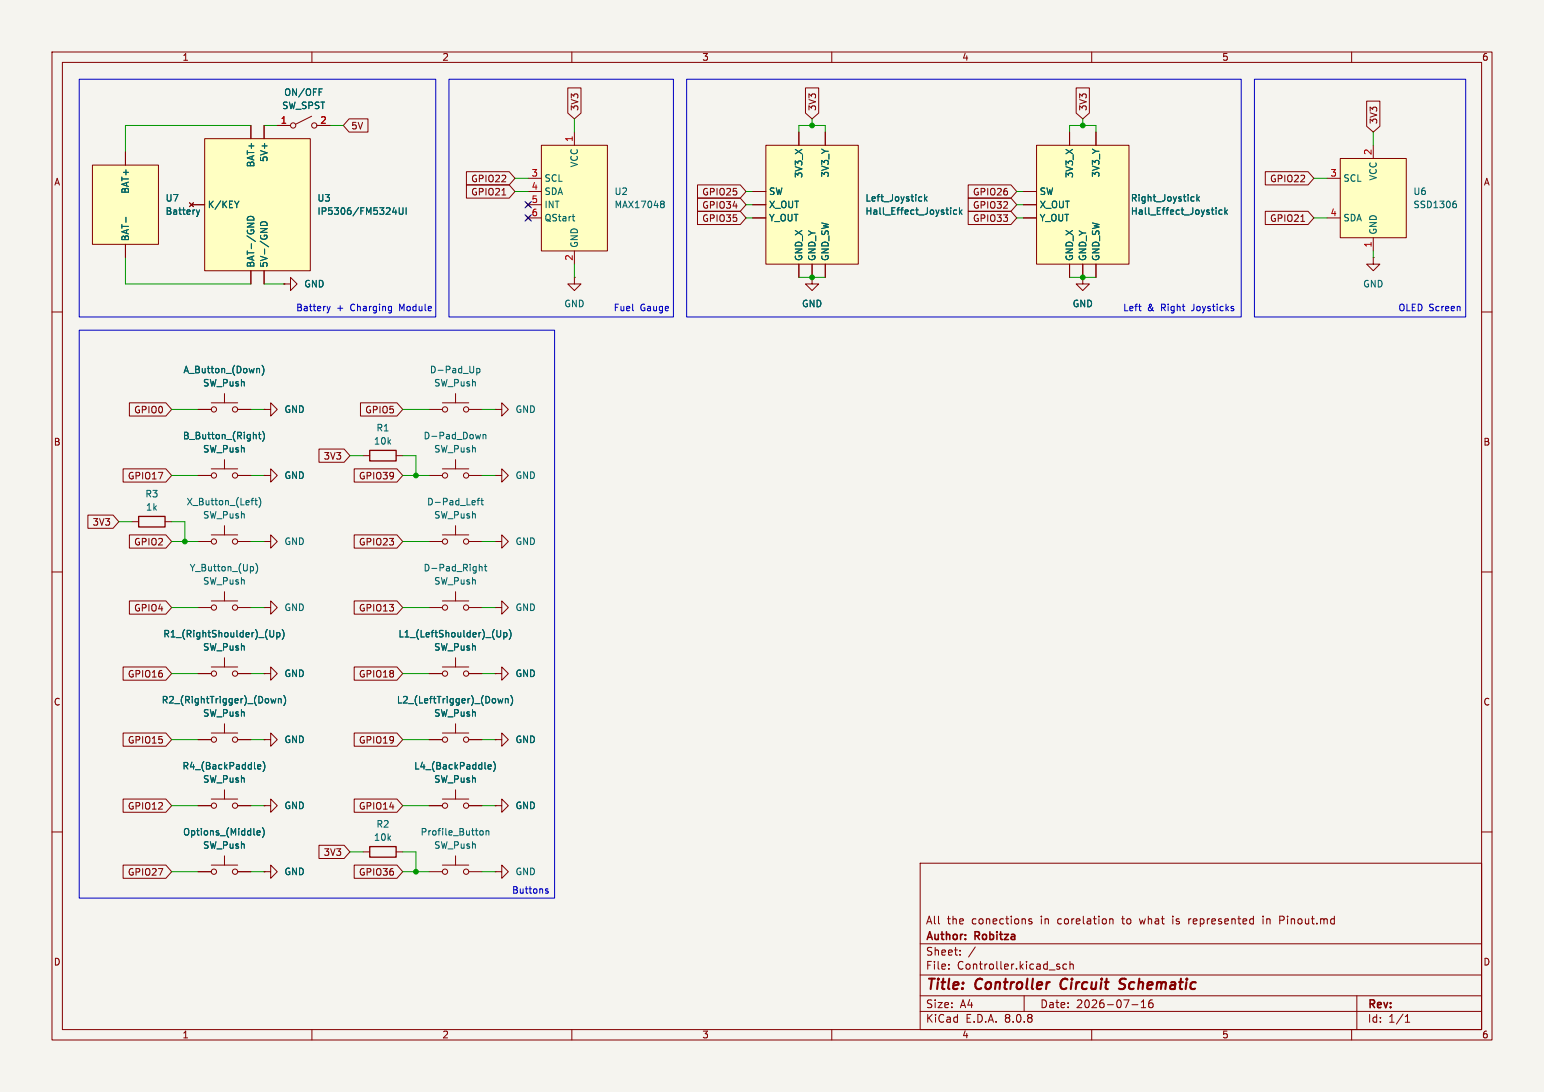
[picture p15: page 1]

IP5306/FM5324UI 5V+ 5V-/GND BAT+ BAT-/GND

Id: 1/1 Title: Controller Circuit Schematic

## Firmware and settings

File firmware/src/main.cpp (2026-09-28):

// Orchestrator: owns the task layout and passes plain data between modules.
//
//   core 1  inputTask  every 1 ms, high priority   InputReader -> ProfileButton / Profiles -> BleOutput
//   core 0  uiTask     every 20 ms, low priority   Display, BatteryMonitor, ConfigMenu, Storage writes, PowerManager
//
// The NimBLE host also runs on core 0, above uiTask, so slow UI work (a full OLED frame is ~23 ms of I2C)
// never delays BLE or input. uiTask is the only user of the I2C bus, so the bus needs no locking.

#include <Arduino.h>
#include <Wire.h>
#include <esp_sleep.h>
#include <esp_system.h>

#include <atomic>

#include "BatteryMonitor.h"
#include "BleOutput.h"
#include "Config.h"
#include "ConfigMenu.h"
#include "Display.h"
#include "InputReader.h"
#include "Log.h"
#include "PowerManager.h"
#include "ProfileButton.h"
#include "Profiles.h"
#include "Storage.h"

namespace {

// What the input task tells the UI task. Written every input cycle, read every UI cycle, under a spinlock
// (a copy of a few bytes, so neither side waits noticeably).
struct Status {
  char profileName[PROFILE_NAME_MAX + 1] = {};
  uint8_t profileNumber = 0;
  uint8_t profileCount = 0;
  uint32_t profileSwitches = 0;
  bool layerActive = false;
  bool toggleActive = false;
  uint32_t lastInputMs = 0;
};

portMUX_TYPE statusLock = portMUX_INITIALIZER_UNLOCKED;
Status sharedStatus;

// Input task only.
uint32_t profileSwitches = 0;
uint32_t lastInputMs = 0;

// ---------------------------------------------------------------------------------------------
// Config menu handoff between the tasks.
//
//   Closed     input task owns the profiles; a Profile hold copies them into menuList and sets Open
//   Open       UI task runs the menu on menuList; input task sends the host a neutral report and forwards inputs
//   Saved      UI task has written menuList to flash; input task takes it into Profiles and sets Closed
//   Discarded  input task keeps its profiles and sets Closed
//
// menuList is only touched by the task the state names, so it needs no lock of its own; the state and the
// forwarded inputs live under statusLock.
enum class MenuState : uint8_t { Closed, Open, Saved, Discarded };

ConfigMenu::Workspace menuList;
MenuState menuState = MenuState::Closed;
ConfigMenu::Input menuInput;       // `pressed` collects presses until the UI task takes them
uint32_t menuPreviousButtons = 0;  // input task only

// UI task only (read once in setup, before the tasks start).
DisplaySettings displaySettings;
PowerSettings powerSettings;

bool recalibrateRequested = false;  // UI task -> input task, under statusLock
std::atomic<bool> poweringOff{false};  // UI task -> input task: stop touching BLE

MenuState readMenuState() {
  portENTER_CRITICAL(&statusLock);
  const MenuState state = menuState;
  portEXIT_CRITICAL(&statusLock);
  return state;
}

void setMenuState(MenuState state) {
  portENTER_CRITICAL(&statusLock);
  menuState = state;
  portEXIT_CRITICAL(&statusLock);
}

void publishStatus() {
  const Profile& profile = Profiles::active();
  Status status;
  memcpy(status.profileName, profile.name, sizeof(status.profileName));
  status.profileNumber = Profiles::activeIndex() + 1;
  status.profileCount = Profiles::count();
  status.profileSwitches = profileSwitches;
  status.layerActive = Profiles::layerActive();
  status.toggleActive = Profiles::toggleActive();
  status.lastInputMs = lastInputMs;

  portENTER_CRITICAL(&statusLock);
  sharedStatus = status;
  portEXIT_CRITICAL(&statusLock);
}

Status readStatus() {
  portENTER_CRITICAL(&statusLock);
  const Status status = sharedStatus;
  portEXIT_CRITICAL(&statusLock);
  return status;
}

// Radial, like the deadzone.
bool stickActive(int16_t x, int16_t y) {
  constexpr int32_t threshold = static_cast<int32_t>(AXIS_MAX) * Config::ACTIVITY_STICK_PERCENT / 100;
  return static_cast<int32_t>(x) * x + static_cast<int32_t>(y) * y >= threshold * threshold;
}

// What keeps the screen and the controller on: any button, or a stick pushed well past its jitter.
bool isActivity(const InputState& input) {
  return input.buttons != 0 || stickActive(input.axis(Axis::LeftX), input.axis(Axis::LeftY)) ||
         stickActive(input.axis(Axis::RightX), input.axis(Axis::RightY));
}

// Settings that live in the profile but are applied by other modules.
void applyActiveProfileSettings() {
  const Profile& profile = Profiles::active();
  for (uint8_t s = 0; s < STICK_COUNT; ++s) InputReader::setDeadzone(static_cast<Stick>(s), profile.deadzonePercent[s]);
  LOG("profile %u/%u: %s", Profiles::activeIndex() + 1, Profiles::count(), profile.name);
}

void handleProfileGesture(const ProfileButton::Event& event) {
  switch (event.gesture) {
    case ProfileButton::Gesture::None: return;
    case ProfileButton::Gesture::Next: Profiles::selectNext(); break;
    case ProfileButton::Gesture::Previous: Profiles::selectPrevious(); break;
    case ProfileButton::Gesture::JumpTo:
      if (event.profileIndex >= Profiles::count()) return;
      Profiles::select(event.profileIndex);
      break;
    case ProfileButton::Gesture::OpenMenu: return;  // handled by openMenu()
  }
  ++profileSwitches;
  applyActiveProfileSettings();
}

// Input task.
void openMenu(const InputState& input) {
  menuList.count = Profiles::count();
  for (uint8_t i = 0; i < menuList.count; ++i) menuList.profiles[i] = Profiles::get(i);
  menuList.active = Profiles::activeIndex();
  menuPreviousButtons = input.buttons;
  portENTER_CRITICAL(&statusLock);
  menuInput = ConfigMenu::Input{};
  menuState = MenuState::Open;
  portEXIT_CRITICAL(&statusLock);
}

// Input task.
void closeMenu() {
  ProfileButton::reset();
  ++profileSwitches;  // the name popup: a clear sign the controller is back in play
  applyActiveProfileSettings();
  setMenuState(MenuState::Closed);
}

// Input task: one cycle while the menu is open (or has just closed).
void menuCycle(MenuState state, const InputState& input, uint32_t nowUs) {
  BleOutput::send(OutputReport{}, nowUs);  // the host sees nothing while the menu is up
  switch (state) {
    case MenuState::Open: {
      portENTER_CRITICAL(&statusLock);
      const bool recalibrate = recalibrateRequested;
      recalibrateRequested = false;
      portEXIT_CRITICAL(&statusLock);
      if (recalibrate) InputReader::recalibrate();  // ~12 ms, fine while the host gets a neutral report

      const uint32_t newlyPressed = input.buttons & ~menuPreviousButtons;
      menuPreviousButtons = input.buttons;
      portENTER_CRITICAL(&statusLock);
      menuInput.held = input.buttons;
      menuInput.pressed |= newlyPressed;
      menuInput.leftX = input.axis(Axis::LeftX);
      menuInput.leftY = input.axis(Axis::LeftY);
      portEXIT_CRITICAL(&statusLock);
      break;
    }
    case MenuState::Saved:
      Profiles::replaceAll(menuList.profiles, menuList.count, menuList.active);
      closeMenu();
      break;
    case MenuState::Discarded:
      Profiles::resync();
      closeMenu();
      break;
    case MenuState::Closed: break;
  }
}

// UI task: the inputs since the last call.
ConfigMenu::Input takeMenuInput() {
  portENTER_CRITICAL(&statusLock);
  const ConfigMenu::Input input = menuInput;
  menuInput.pressed = 0;
  portEXIT_CRITICAL(&statusLock);
  return input;
}

// UI task. Slots first, then the count (see Storage.h). Slots flash doesn't hold yet are written too, so the first
// save after running on the presets stores the whole list.
void saveMenuList() {
  const uint8_t stored = Storage::savedProfileCount();
  bool ok = true;
  uint8_t written = 0;
  for (uint8_t i = 0; i < menuList.count; ++i) {
    if ((menuList.changedSlots & (1u << i)) == 0 && i < stored) continue;
    ok = Storage::saveProfile(i, menuList.profiles[i]) && ok;
    ++written;
  }
  ok = Storage::saveProfileCount(menuList.count) && ok;
  if (menuList.displayChanged) {
    ok = Storage::saveDisplaySettings(menuList.display) && ok;
    displaySettings = menuList.display;
  }
  if (menuList.powerChanged) {
    ok = Storage::savePowerSettings(menuList.power) && ok;
    powerSettings = menuList.power;
  }
  LOG("Storage: %u profile(s)%s%s written, %s", written, menuList.displayChanged ? " + display settings" : "",
      menuList.powerChanged ? " + power settings" : "", ok ? "OK" : "FAILED");
}

// UI task. Deep sleep with no wake-up source: the load drops far below the IP5306's threshold, the IP5306 switches
// the 5 V off, and the power switch (off, on) starts the controller again.
[[noreturn]] void powerOff() {
  poweringOff = true;
  vTaskDelay(pdMS_TO_TICKS(Config::INPUT_SCAN_PERIOD_MS * 5));  // any report in flight finishes
  Display::powerOff();
  BleOutput::shutdown();
  vTaskDelay(pdMS_TO_TICKS(Config::POWER_OFF_DISCONNECT_MS));
  LOG("power: deep sleep; toggle the power switch to start again");
  Serial.flush();
  esp_deep_sleep_start();
}

// UI task: the full-screen alert for a PowerManager decision.
void showPowerAlert(const PowerManager::Decision& power) {
  char big[8];
  switch (power.alert) {
    case PowerManager::Alert::AutoOffCountdown:
      snprintf(big, sizeof(big), "%u s", power.secondsLeft);
      Display::showAlert("Powering off in", big, "press any button");
      break;
    case PowerManager::Alert::BatteryCritical:
      snprintf(big, sizeof(big), "%u%%", power.batteryPercent);
      Display::showAlert("Battery critical", big, "charge now");
      break;
    case PowerManager::Alert::BatteryEmpty:
      snprintf(big, sizeof(big), "%u%%", power.batteryPercent);
      Display::showAlert("Battery empty", big, "powering off");
      break;
    case PowerManager::Alert::None: break;
  }
}

#ifdef CONTROLLER_DEBUG
// A power-off that wasn't the switch shows up here (brownout: loose board or weak battery).
const char* resetReasonName(esp_reset_reason_t reason) {
  switch (reason) {
    case ESP_RST_POWERON: return "power-on";
    case ESP_RST_BROWNOUT: return "BROWNOUT (supply voltage dipped)";
    case ESP_RST_SW: return "software restart";
    case ESP_RST_PANIC: return "CRASH (panic)";
    case ESP_RST_INT_WDT:
    case ESP_RST_TASK_WDT:
    case ESP_RST_WDT: return "WATCHDOG";
    case ESP_RST_EXT: return "reset pin";
    default: return "other";
  }
}
#endif

void inputTask(void*) {
  TickType_t lastWake = xTaskGetTickCount();
  uint32_t previousStartUs = micros();
  for (;;) {
    vTaskDelayUntil(&lastWake, pdMS_TO_TICKS(Config::INPUT_SCAN_PERIOD_MS));
    const uint32_t startUs = micros();
    const float dtS = (startUs - previousStartUs) * 1e-6f;
    previousStartUs = startUs;
    if (poweringOff) continue;  // the UI task is shutting the controller down

    const InputState& input = InputReader::read(startUs);
    if (isActivity(input)) lastInputMs = millis();

    const MenuState menu = readMenuState();
    if (menu != MenuState::Closed) {
      menuCycle(menu, input, startUs);
    } else {
      uint32_t suppressedButtons = 0;
      const ProfileButton::Event gesture = ProfileButton::update(input, millis(), suppressedButtons);
      if (gesture.gesture == ProfileButton::Gesture::OpenMenu) openMenu(input);
      handleProfileGesture(gesture);
      InputState forHost = input;
      forHost.buttons &= ~suppressedButtons;
      BleOutput::send(Profiles::apply(forHost, startUs, dtS), startUs);
    }
    publishStatus();
  }
}

void uiTask(void*) {
  // Started here rather than in setup() so the I2C interrupts are allocated on this core, away from input.
  Wire.begin(Config::I2C_SDA, Config::I2C_SCL, Config::I2C_FREQUENCY_HZ);
  BatteryMonitor::begin();
  Display::begin();
  Display::applySettings(displaySettings);

  uint8_t batteryReportedToHost = UINT8_MAX;
  // The active profile is saved once it has stayed put for a while, so flicking through profiles doesn't write
  // flash on every press (each write briefly stalls both cores).
  uint8_t savedProfileNumber = readStatus().profileNumber;
  uint8_t seenProfileNumber = savedProfileNumber;
  uint32_t profileSeenSinceMs = millis();
  bool menuRunning = false;
  TickType_t lastWake = xTaskGetTickCount();
  for (;;) {
    vTaskDelayUntil(&lastWake, pdMS_TO_TICKS(Config::UI_TASK_PERIOD_MS));
    const uint32_t nowMs = millis();

    const bool newBatteryReading = BatteryMonitor::update(nowMs);
    const BatteryStatus battery = BatteryMonitor::status();
    const bool connected = BleOutput::isConnected();
    // Sent once per connection and on every change; the host reads it when it connects.
    if (!connected) {
      batteryReportedToHost = UINT8_MAX;
    } else if (battery.present && battery.percent != batteryReportedToHost) {
      BleOutput::setBatteryLevel(battery.percent);
      batteryReportedToHost = battery.percent;
    }

    const Status status = readStatus();
    if (status.profileNumber != seenProfileNumber) {
      seenProfileNumber = status.profileNumber;
      profileSeenSinceMs = nowMs;
    }
    if (seenProfileNumber != savedProfileNumber && nowMs - profileSeenSinceMs >= Config::ACTIVE_PROFILE_SAVE_DELAY_MS) {
      Storage::saveActiveIndex(seenProfileNumber - 1);
      savedProfileNumber = seenProfileNumber;
    }

    const PowerManager::Decision power =
        PowerManager::update(nowMs, status.lastInputMs, connected, battery, newBatteryReading, powerSettings);
    if (power.powerOff) powerOff();
    const bool alert = power.alert != PowerManager::Alert::None;

    if (readMenuState() == MenuState::Open) {
      if (!menuRunning) {
        menuList.display = displaySettings;
        menuList.power = powerSettings;
        ConfigMenu::open(menuList, nowMs);
        menuRunning = true;
      }
      ConfigMenu::Input input = takeMenuInput();
      // The press that wakes the screen or cancels an alert does nothing else.
      input.screenWasOff =
          alert || (Display::asleep() && (input.held != 0 || input.pressed != 0 || stickActive(input.leftX, input.leftY)));
      const ConfigMenu::Request request = ConfigMenu::update(input, nowMs);
      // Display settings are previewed while they're edited; Discard puts the saved ones back.
      Display::applySettings(request == ConfigMenu::Request::Discard ? displaySettings : menuList.display);
      if (alert) showPowerAlert(power);
      else Display::showMenu(ConfigMenu::view(), status.lastInputMs, nowMs);  // "Saving..." before the flash writes
      switch (request) {
        case ConfigMenu::Request::Save:
          saveMenuList();
          menuRunning = false;
          setMenuState(MenuState::Saved);
          break;
        case ConfigMenu::Request::Discard:
          menuRunning = false;
          setMenuState(MenuState::Discarded);
          break;
        case ConfigMenu::Request::ForgetPairings: BleOutput::forgetPairings(); break;
        case ConfigMenu::Request::RecalibrateSticks:
          portENTER_CRITICAL(&statusLock);
          recalibrateRequested = true;
          portEXIT_CRITICAL(&statusLock);
          break;
        case ConfigMenu::Request::None: break;
      }
      continue;
    }

    if (alert) {
      showPowerAlert(power);
      continue;
    }

    Display::State screen;
    memcpy(screen.profileName, status.profileName, sizeof(screen.profileName));
    screen.profileNumber = status.profileNumber;
    screen.profileCount = status.profileCount;
    screen.profileSwitches = status.profileSwitches;
    screen.layerActive = status.layerActive;
    screen.toggleActive = status.toggleActive;
    screen.bleConnected = connected;
    screen.battery = battery;
    screen.lastInputMs = status.lastInputMs;
    Display::update(screen, nowMs);
  }
}

}  // namespace

void setup() {
  Serial.setTxBufferSize(1024);
  Serial.begin(115200);
  LOG("reset reason: %s", resetReasonName(esp_reset_reason()));

  // Storage first: the profiles and the last active profile come from it.
  Storage::begin();
  Profiles::begin(Storage::loadProfiles, Storage::loadActiveIndex());
  displaySettings = Storage::loadDisplaySettings();
  powerSettings = Storage::loadPowerSettings();
  InputReader::begin();
  ProfileButton::begin();
  BleOutput::begin();
  PowerManager::begin();
  applyActiveProfileSettings();
  publishStatus();
  // BatteryMonitor and Display start in uiTask, which owns the I2C bus.

  xTaskCreatePinnedToCore(inputTask, "input", Config::INPUT_TASK_STACK_BYTES, nullptr, Config::INPUT_TASK_PRIORITY,
                          nullptr, Config::INPUT_TASK_CORE);
  xTaskCreatePinnedToCore(uiTask, "ui", Config::UI_TASK_STACK_BYTES, nullptr, Config::UI_TASK_PRIORITY, nullptr,
                          Config::UI_TASK_CORE);

  LOG("boot complete");
}

void loop() {
  // All work runs in the tasks created in setup().
  vTaskDelete(nullptr);
}

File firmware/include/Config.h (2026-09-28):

#pragma once

// Every pin, address, timing and threshold lives here. Pin source of truth: Pinout.md.

#include <Arduino.h>
#include "ControllerTypes.h"

namespace Config {

// ---------------------------------------------------------------------------------------------
// Buttons (all active LOW)

struct ButtonPin {
  uint8_t gpio;
  bool externalPullup;  // input-only GPIO36/39 have no internal pull-up; GPIO2 has an external 1k
  bool glitchProne;     // ESP32 errata: GPIO36/39 can read LOW for ~80 ns when the ADC powers up
};

// Indexed by Button.
constexpr ButtonPin BUTTON_PINS[BUTTON_COUNT] = {
  {0, false, false},   // A          strapping pin: don't hold at boot/flash
  {17, false, false},  // B
  {2, true, false},    // X          strapping pin, on-board LED
  {4, false, false},   // Y
  {5, false, false},   // D-Up       strapping pin
  {39, true, true},    // D-Down     input-only
  {23, false, false},  // D-Left
  {13, false, false},  // D-Right
  {18, false, false},  // L1
  {19, false, false},  // L2         digital trigger
  {25, false, false},  // L3
  {14, false, false},  // L4         back paddle
  {16, false, false},  // R1
  {15, false, false},  // R2         digital trigger, strapping pin
  {26, false, false},  // R3
  {12, false, false},  // R4         back paddle, strapping pin (must not be HIGH at boot)
  {27, false, false},  // Options
  {36, true, true},    // Profile    input-only
};

// ---------------------------------------------------------------------------------------------
// Sticks (ADC1, safe to use with BLE)

struct AxisPin {
  uint8_t gpio;
  bool invert;  // raw X falls when pushed right, raw Y rises when pushed up; output is +X right, +Y up
};

// Indexed by Axis.
constexpr AxisPin AXIS_PINS[AXIS_COUNT] = {
  {34, true},   // Left X   ADC1_CH6
  {35, false},  // Left Y   ADC1_CH7
  {32, true},   // Right X  ADC1_CH4
  {33, false},  // Right Y  ADC1_CH5
};

constexpr int ADC_MAX = 4095;  // 12-bit, 11 dB attenuation; the sticks saturate both ends before full travel
constexpr int ADC_MID = 2048;
constexpr uint8_t STICK_OVERSAMPLING = 4;        // ADC reads averaged per axis per scan
constexpr uint16_t STICK_CENTER_SAMPLES = 64;    // reads averaged for the power-on center
constexpr int STICK_CENTER_MAX_OFFSET = 400;     // raw counts; a center farther from ADC_MID means a touched stick
constexpr uint8_t STICK_DEADZONE_PERCENT = 5;
constexpr uint8_t STICK_DEADZONE_MAX_PERCENT = 50;

// ---------------------------------------------------------------------------------------------
// I2C bus, shared by the OLED and the fuel gauge. Only the UI task may use it.

constexpr uint8_t I2C_SDA = 21;
constexpr uint8_t I2C_SCL = 22;
constexpr uint32_t I2C_FREQUENCY_HZ = 400000;
constexpr uint8_t OLED_ADDRESS = 0x3C;
constexpr uint8_t FUEL_GAUGE_ADDRESS = 0x36;

// ---------------------------------------------------------------------------------------------
// Input timing

constexpr uint32_t INPUT_SCAN_PERIOD_MS = 1;
constexpr uint32_t DEBOUNCE_LOCKOUT_US = 5000;   // eager debounce: press counts at once, then the pin is ignored
constexpr uint32_t MIN_REPORT_INTERVAL_US = 3750;  // at most ~2 reports per 7.5 ms connection event
constexpr uint32_t PROFILE_HOLD_MS = 3000;       // hold Profile this long to enter config mode
static_assert(DEBOUNCE_LOCKOUT_US >= MIN_REPORT_INTERVAL_US,
              "every press and release must outlast the report rate limit, or a quick tap could be lost");

// ---------------------------------------------------------------------------------------------
// Profiles

constexpr uint32_t PROFILE_DOUBLE_PRESS_MS = 300;  // a second Profile press within this goes back a profile
constexpr uint32_t ACTIVE_PROFILE_SAVE_DELAY_MS = 3000;  // remember the active profile once it stays this long
constexpr float STICK_DIRECTION_PRESS = 0.50f;     // Directions mode: fraction of full deflection that presses
constexpr float STICK_DIRECTION_RELEASE = 0.35f;   // ...and releases (hysteresis, no chatter at the threshold)
constexpr float MOUSE_COUNTS_PER_S_PER_SENSITIVITY = 300.0f;  // at full deflection; sensitivity 5 = 1500 counts/s
constexpr float MOUSE_CURVE_EXPONENT = 2.0f;       // speed = deflection^exponent: precise near the center
constexpr float SCROLL_STEPS_PER_S_PER_SENSITIVITY = 4.0f;    // at full deflection; sensitivity 5 = 20 steps/s
constexpr uint8_t SENSITIVITY_MIN = 1;
constexpr uint8_t SENSITIVITY_MAX = 10;
constexpr uint32_t SCROLL_REPEAT_DELAY_MS = 300;   // a Scroll action held this long starts repeating...
constexpr uint32_t SCROLL_REPEAT_INTERVAL_MS = 60; // ...one step every this often
constexpr uint8_t TURBO_DEFAULT_HZ = 10;
constexpr uint8_t TURBO_MIN_HZ = 1;
constexpr uint8_t TURBO_MAX_HZ = 20;
static_assert(1000000 / (2 * TURBO_MAX_HZ) >= MIN_REPORT_INTERVAL_US, "each turbo pulse must reach the host");

// ---------------------------------------------------------------------------------------------
// Display and battery (UI task)
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

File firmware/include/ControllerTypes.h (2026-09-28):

#pragma once

// Plain data shared between modules. Modules depend on these types, not on each other.

#include <stdint.h>

// Physical buttons. The order is the index into Config::BUTTON_PINS and the bit position in InputState::buttons.
enum class Button : uint8_t {
  A, B, X, Y,
  DpadUp, DpadDown, DpadLeft, DpadRight,
  L1, L2, L3, L4,
  R1, R2, R3, R4,
  Options, Profile,
  Count
};
constexpr uint8_t BUTTON_COUNT = static_cast<uint8_t>(Button::Count);

constexpr uint32_t buttonBit(Button button) { return 1u << static_cast<uint8_t>(button); }

enum class Axis : uint8_t { LeftX, LeftY, RightX, RightY, Count };
constexpr uint8_t AXIS_COUNT = static_cast<uint8_t>(Axis::Count);

enum class Stick : uint8_t { Left, Right, Count };
constexpr uint8_t STICK_COUNT = static_cast<uint8_t>(Stick::Count);

constexpr int16_t AXIS_MAX = 32767;  // full deflection; the range is symmetric (-AXIS_MAX..AXIS_MAX)

// Every physical input after debouncing and stick processing.
// Axes are -AXIS_MAX..AXIS_MAX with +X = right and +Y = up; outputs that use another convention convert at their end.
struct InputState {
  uint32_t buttons = 0;  // bit n set = Button n pressed
  int16_t axes[AXIS_COUNT] = {};

  bool isPressed(Button button) const { return buttons & buttonBit(button); }
  int16_t axis(Axis a) const { return axes[static_cast<uint8_t>(a)]; }
};

// ---------------------------------------------------------------------------------------------
// Outputs: everything the host should see after the active profile has been applied.
// Same axis convention as InputState (+X right, +Y up); BleOutput converts to what each HID device expects.

// Xbox Series controller buttons, as XInput games see them.
enum class XboxButton : uint8_t { A, B, X, Y, LB, RB, View, Menu, Guide, LS, RS, Share, Count };

enum class DpadDirection : uint8_t { Up, Down, Left, Right, Count };

constexpr uint16_t TRIGGER_MAX = 1023;

struct GamepadReport {
  uint16_t buttons = 0;  // bit n = XboxButton n
  uint8_t dpad = 0;      // bit n = DpadDirection n
  int16_t leftX = 0, leftY = 0, rightX = 0, rightY = 0;
  uint16_t leftTrigger = 0, rightTrigger = 0;  // 0..TRIGGER_MAX
};

constexpr uint8_t MAX_KEYS = 6;  // simultaneous non-modifier keys in a HID keyboard report

struct KeyboardReport {
  uint8_t modifiers = 0;      // HID modifier bits (Ctrl, Shift, Alt, GUI; left and right)
  uint8_t keys[MAX_KEYS] = {};  // HID usage IDs, 0 = empty slot
};

constexpr uint8_t MAX_CONSUMER_KEYS = 2;  // media/launch/browser keys held at the same time

enum class SystemKey : uint8_t { PowerDown, Sleep, WakeUp, Count };

enum class MouseButton : uint8_t { Left, Right, Middle, Back, Forward, Count };

// Mouse motion is a rate, so profiles express it as the fraction of counts to move during this input cycle;
// BleOutput accumulates the fractions and sends whole counts.
struct MouseReport {
  uint8_t buttons = 0;  // bit n = MouseButton n
  float moveX = 0.0f;   // counts this cycle, +X right
  float moveY = 0.0f;   // counts this cycle, +Y up
  float wheel = 0.0f;   // steps this cycle, + = scroll up
  float pan = 0.0f;     // steps this cycle, + = scroll right
};

struct OutputReport {
  GamepadReport gamepad;
  KeyboardReport keyboard;
  uint16_t consumer[MAX_CONSUMER_KEYS] = {};  // HID consumer-page usages (media, launch, browser...), 0 = none
  uint8_t system = 0;                         // bit n = SystemKey n
  MouseReport mouse;
};

// ---------------------------------------------------------------------------------------------
// Battery

struct BatteryStatus {
  bool present = false;   // the fuel gauge answered
  uint8_t percent = 0;    // 0-100
  bool charging = false;  // charge rate above Config::BATTERY_CHARGING_RATE
};

// ---------------------------------------------------------------------------------------------
// Controller-wide display settings (not per profile): Controller page of the config menu, kept in flash.
// The defaults are what the controller used before these were settings (checked in Config.h).

struct DisplaySettings {
  uint8_t brightness = 4;  // level 1..Config::DISPLAY_BRIGHTNESS_LEVELS
  uint8_t screenOff = 1;   // index into Config::DISPLAY_SLEEP_OPTIONS_S
  bool namePopup = true;   // the new profile's name full screen after a switch
};

// Controller-wide auto power-off (PowerManager): minutes without activity, as indexes into
// Config::AUTO_OFF_OPTIONS_MIN. Defaults checked in Config.h.
struct PowerSettings {
  uint8_t offWhenConnected = 3;  // while a host is connected
  uint8_t offWhenOffline = 3;    // while nothing is connected
};

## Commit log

2026-07-07 First Commit
    Started adding the files for the chosen repository structure and added the content created before the repository.
    [black_L1.stl, black_L2.stl, black_L4.stl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]
2026-07-18 Add project documentation and hardware schematic
    - Added .gitignore
    - Added Bluetooth, Features, Hardware, Software, and Future Plans documentation
    - Added CONTRIBUTING.md
    - Added the KiCad schematic and PDF export
    - Updated the hardware pinout documentation
    [Controller.kicad_sch]
2026-07-19 Restructure project documentation and add pinout reference
    - Consolidated project documentation to reduce duplication and improve maintainability.
    - Merged Features.md into README.md.
    - Merged Bluetooth.md into Software.md.
    - Merged Battery.md into Hardware.md.
    - Added Architecture.md documenting the overall firmware and hardware architecture.
    - Added Pinout.png to hardware/pinout/ as a visual reference for board orientation and component placement.
    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
2026-09-25 Finalize hardware wiring, pinouts, and test firmware
    - Complete physical wiring, component assembly, and enclosure fit adjustments.
    - Update pin assignments (swap L3/R3, reassign GPIO3 to GPIO39 with a 10 kΩ pull-up).
    - Add 1 kΩ pull-up resistor to GPIO2 to resolve constant-press hardware issue.
    - Add dedicated PlatformIO test firmware to validate buttons and analog axes.
    - Update electrical schematics, pinout documentation, and diagrams.
    - Add media files (images and video) demonstrating wiring, placement, and firmware test.
    - Document progress and findings in DevelopmentLog.md.
    [Controller.kicad_sch]
2026-09-28 Firmware 1.0.0: modular PlatformIO firmware
    Complete rewrite of the controller firmware as a modular PlatformIO project,
    tested on the real hardware with Windows 11.
    Firmware (firmware/):
    - Native XInput (Xbox Series controller) plus keyboard, mouse, media and
    system keys on one Bluetooth LE connection (ESP32-BLE-CompositeHID,
    vendored in lib/ with local changes)
    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
    [partitions.csv]
